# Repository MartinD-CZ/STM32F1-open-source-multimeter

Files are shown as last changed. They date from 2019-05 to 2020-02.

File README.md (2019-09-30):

# STM32 OpenSource Multimeter
*see the article [here](http://embedblog.eu/?p=438) or the video [here](https://youtu.be/qQX5iS70-mg)*
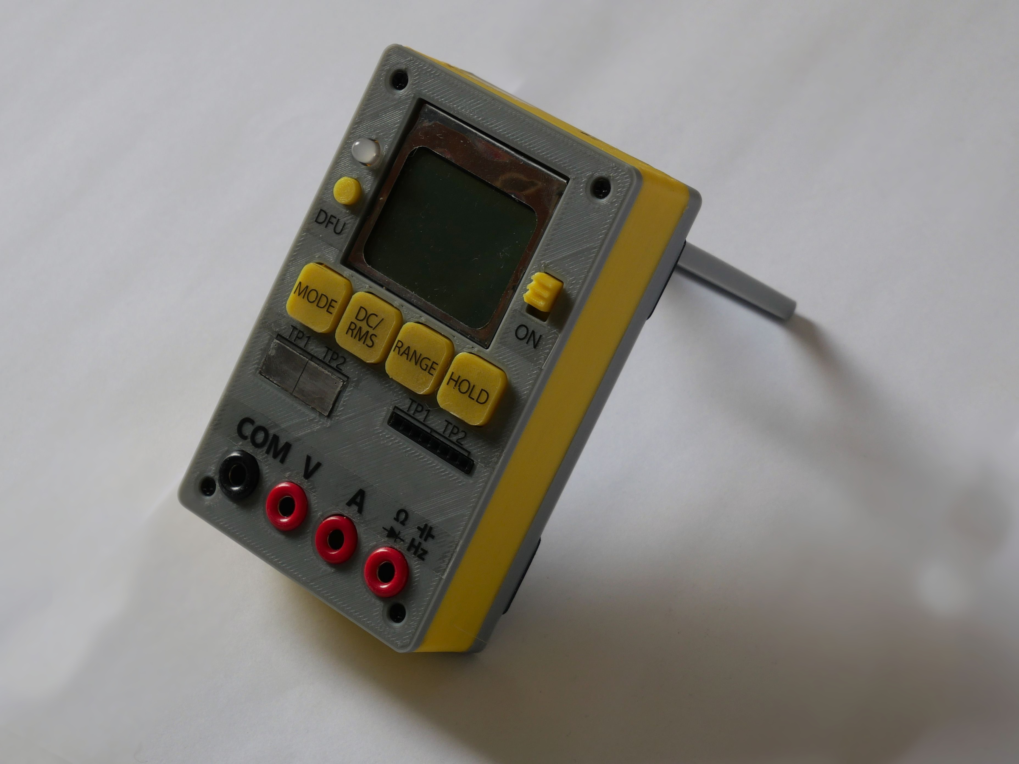
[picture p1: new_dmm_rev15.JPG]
A picture of the finished device


## Specs (revision 1.5 - latest stable)
1. voltage measurement: ±60 V, ±6 V, ±600 mV, ±60 m ranges, with DC or RMS data acquisition
2. current measurement: ±250 or ±2500 mA ranges, again with DC or RMS
3. can measure voltage and current simultaneously and display the product, ie power
4. measures continuity and displays the resistance and voltage drop
5. can perform simple component testing
6. frequency measurement up to 10 MHz

Additional features: isolated USB serial port; ; 2 kB EEPROM; 4 bit expansion port; battery voltage measurement & charging via USB; firmware update via USB; integrated kickstand; hold function

*Note: when this project started, it used STM32F1. Now it uses STM32F3, but I cannot rename the repository, so I hope it won't mislead anyone.*

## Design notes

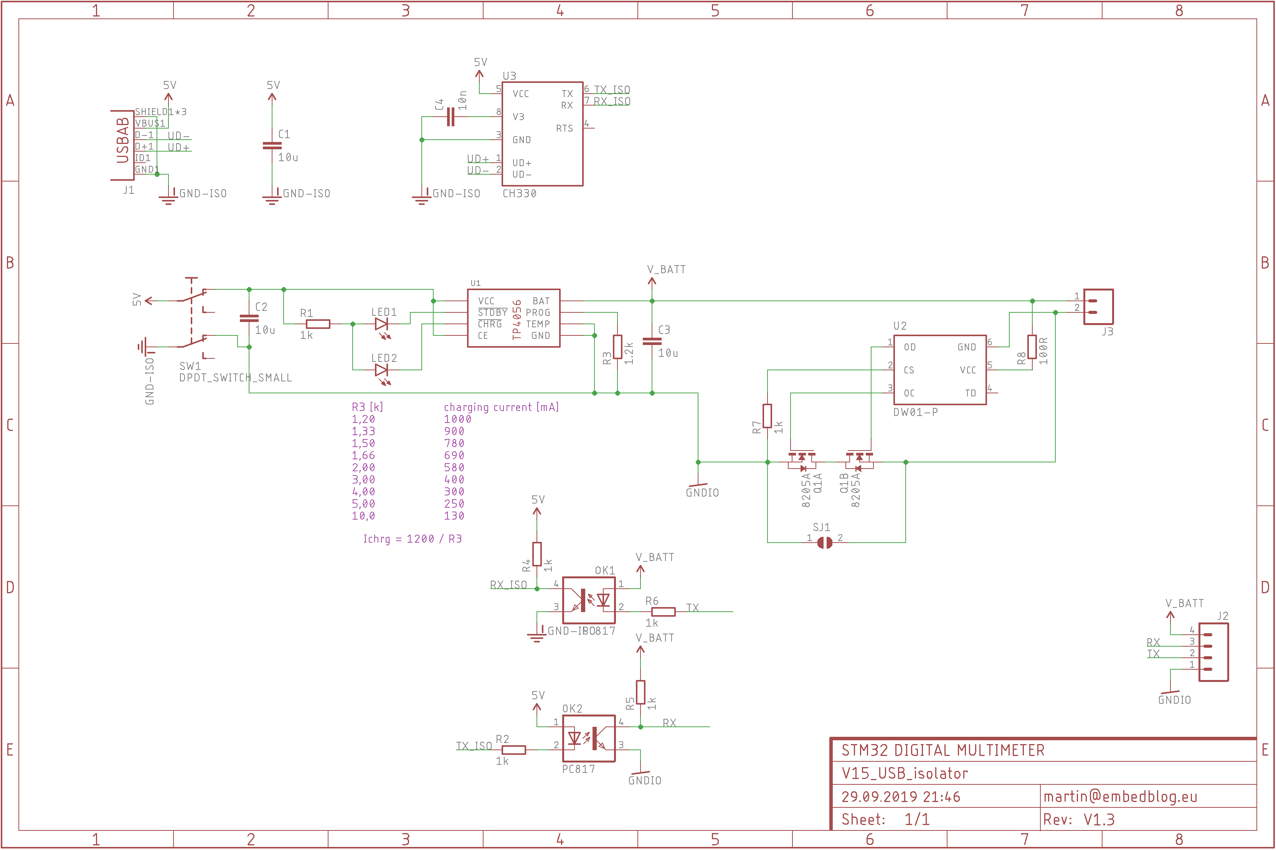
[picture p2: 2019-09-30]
hardware/schematics_USB_isolator.png

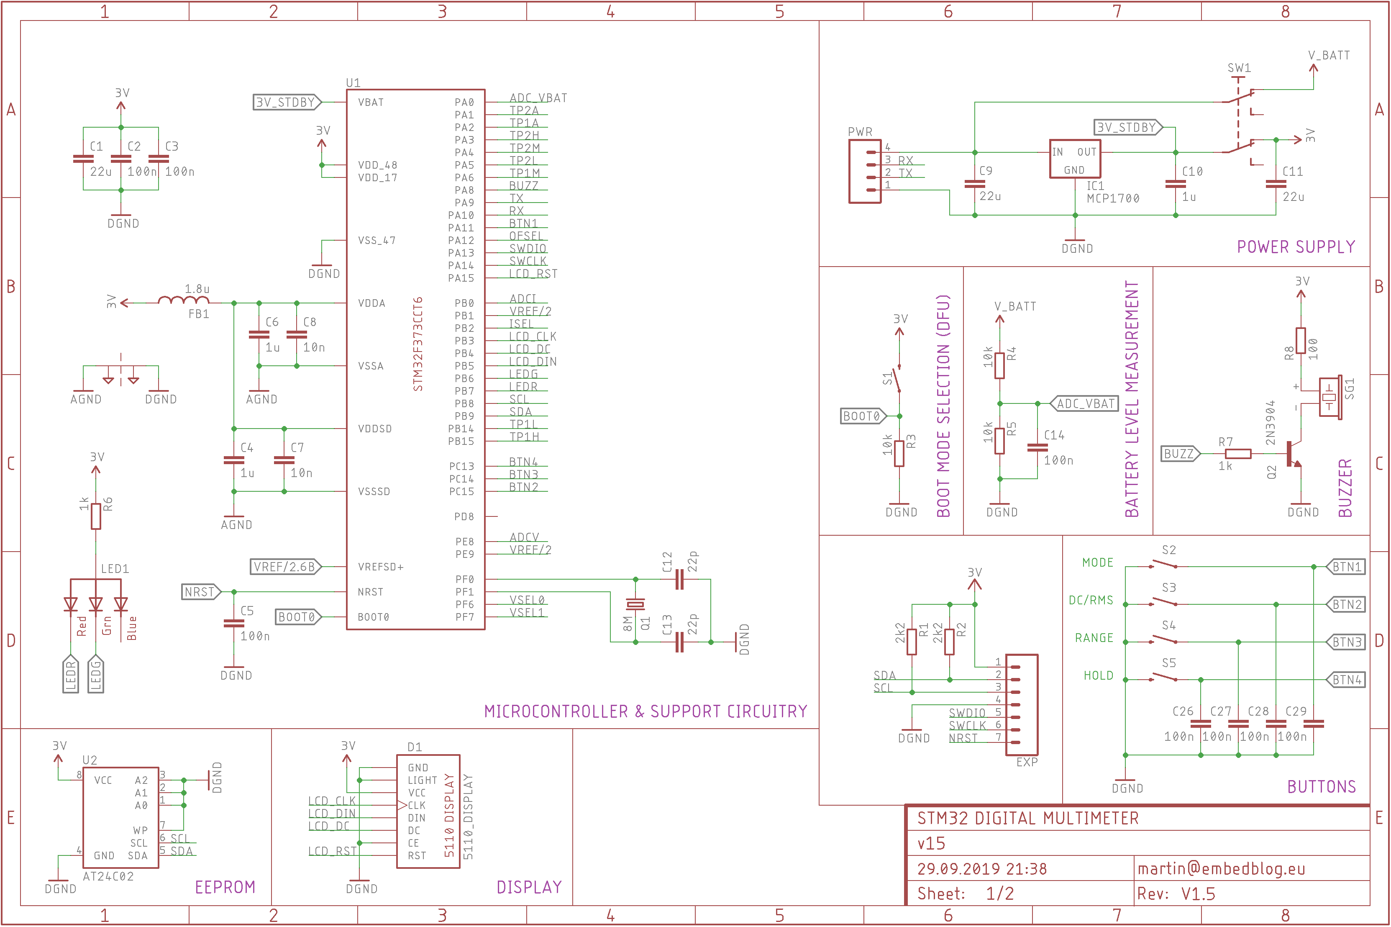
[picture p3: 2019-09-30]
hardware/schematics_sheet1.png

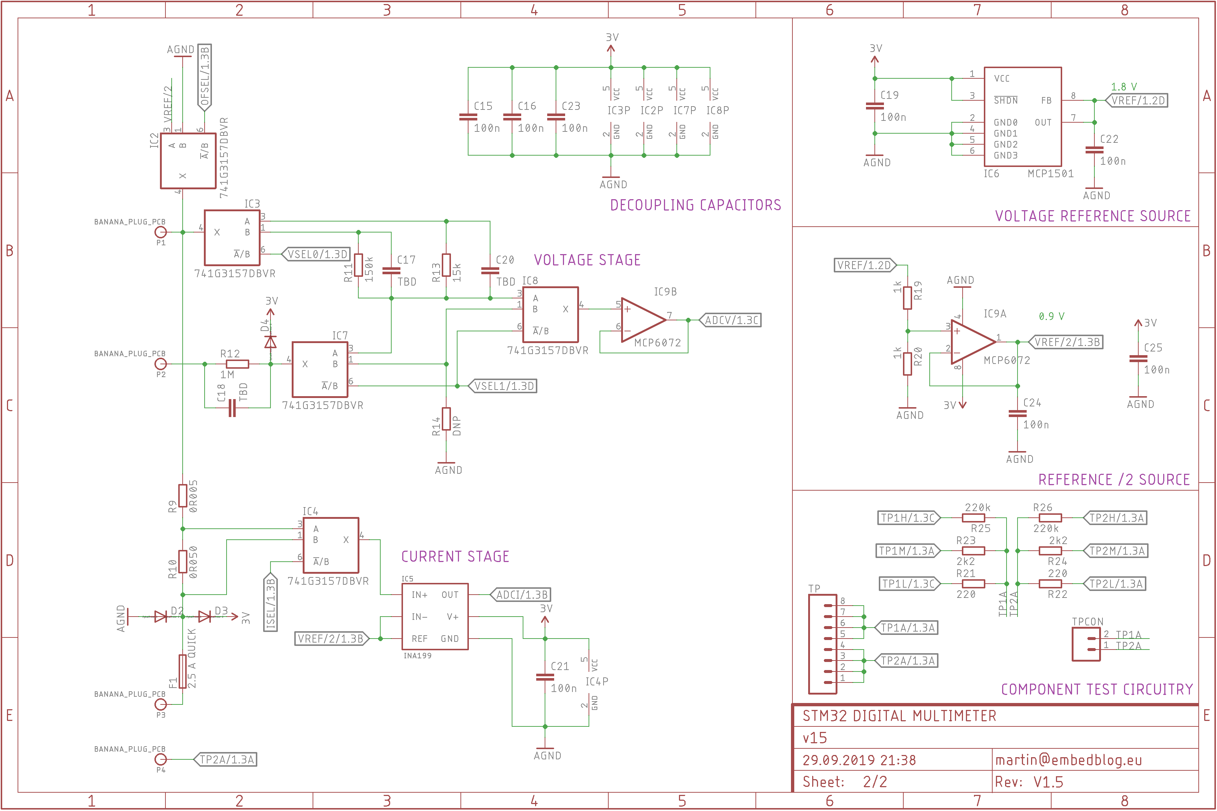
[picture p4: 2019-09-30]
hardware/schematics_sheet2.png

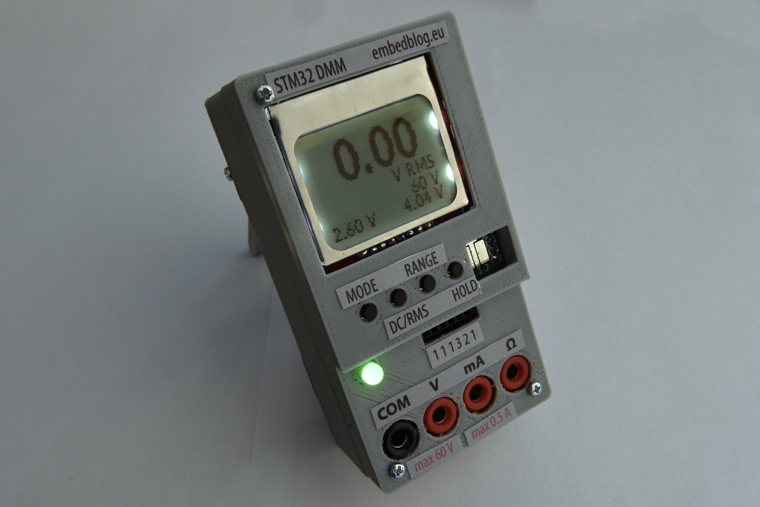
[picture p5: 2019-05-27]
dmm.JPG

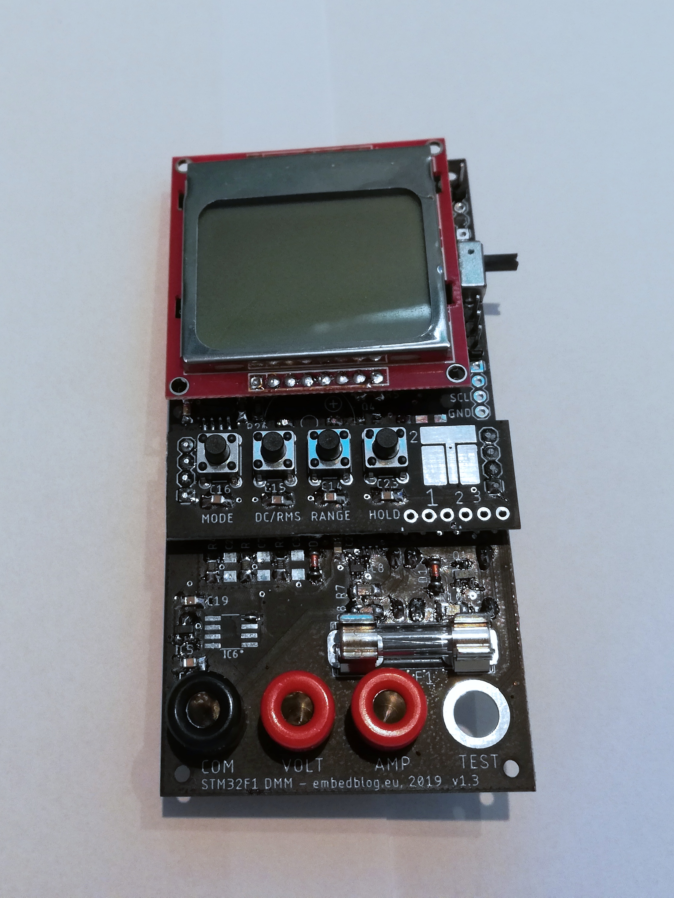
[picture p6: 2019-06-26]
dmm_rev13.JPG

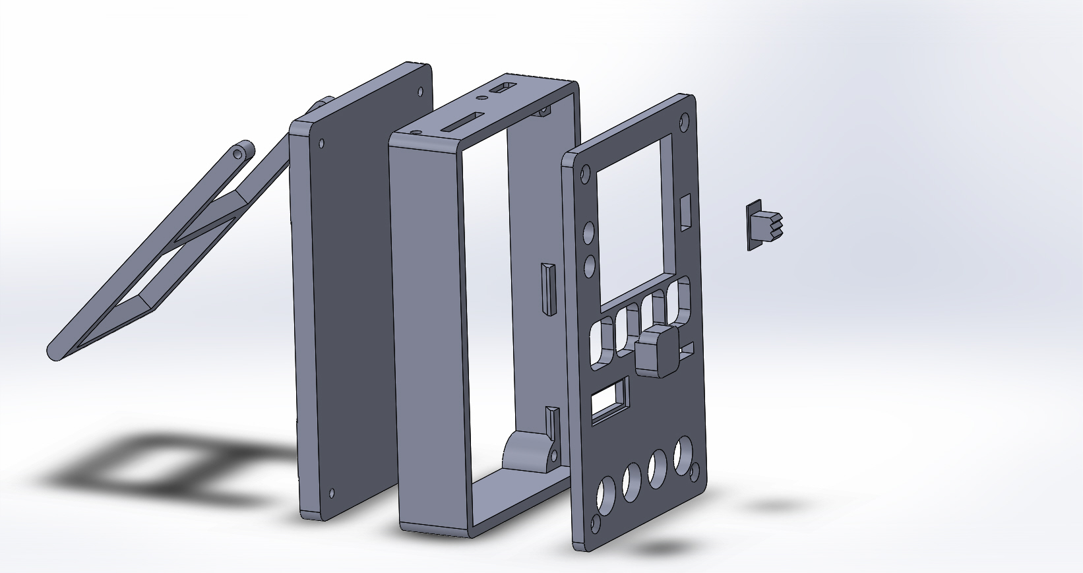
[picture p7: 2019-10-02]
case/case_exploded.JPG

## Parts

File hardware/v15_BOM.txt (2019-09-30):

Part  Value                           Device                          Package                  Description                                                                                                     MF MPN OC_FARNELL OC_NEWARK PROD_ID     SF_ID     SF_SKU   
C1    22u                             C-EUC1206                       C1206                    CAPACITOR, European symbol                                                                                                                                                 
C2    100n                            C-EUC1206                       C1206                    CAPACITOR, European symbol                                                                                                                                                 
C3    100n                            C-EUC1206                       C1206                    CAPACITOR, European symbol                                                                                                                                                 
C4    1u                              C-EUC1206                       C1206                    CAPACITOR, European symbol                                                                                                                                                 
C5    100n                            C-EUC1206                       C1206                    CAPACITOR, European symbol                                                                                                                                                 
C6    1u                              C-EUC1206                       C1206                    CAPACITOR, European symbol                                                                                                                                                 
C7    10n                             C-EUC1206                       C1206                    CAPACITOR, European symbol                                                                                                                                                 
C8    10n                             C-EUC1206                       C1206                    CAPACITOR, European symbol                                                                                                                                                 
C9    22u                             C-EUC1206                       C1206                    CAPACITOR, European symbol                                                                                                                                                 
C10   1u                              C-EUC1206                       C1206                    CAPACITOR, European symbol                                                                                                                                                 
C11   22u                             C-EUC1206                       C1206                    CAPACITOR, European symbol                                                                                                                                                 
C12   22p                             C-EUC1206                       C1206                    CAPACITOR, European symbol                                                                                                                                                 
C13   22p                             C-EUC1206                       C1206                    CAPACITOR, European symbol                                                                                                                                                 
C14   100n                            C-EUC1206                       C1206                    CAPACITOR, European symbol                                                                                                                                                 
C15   100n                            CAP1206                         1206                     Capacitor                                                                                                                                                                  
C16   100n                            CAP1206                         1206                     Capacitor                                                                                                                                                                  
C17   TBD                             CAP1206                         1206                     Capacitor                                                                                                                                                                  
C18   TBD                             CAP1206                         1206                     Capacitor                                                                                                                                                                  
C19   100n                            C-EUC1206                       C1206                    CAPACITOR, European symbol                                                                                                                                                 
C20   TBD                             CAP1206                         1206                     Capacitor                                                                                                                                                                  
C21   100n                            CAP1206                         1206                     Capacitor                                                                                                                                                                  
C22   100n                            C-EUC1206                       C1206                    CAPACITOR, European symbol                                                                                                                                                 
C23   100n                            CAP1206                         1206                     Capacitor                                                                                                                                                                  
C24   100n                            C-EUC1206                       C1206                    CAPACITOR, European symbol                                                                                                                                                 
C25   100n                            C-EUC1206                       C1206                    CAPACITOR, European symbol                                                                                                                                                 
C26   100n                            C-EUC1206                       C1206                    CAPACITOR, European symbol                                                                                                                                                 
C27   100n                            C-EUC1206                       C1206                    CAPACITOR, European symbol                                                                                                                                                 
C28   100n                            C-EUC1206                       C1206                    CAPACITOR, European symbol                                                                                                                                                 
C29   100n                            C-EUC1206                       C1206                    CAPACITOR, European symbol                                                                                                                                                 
D1    5110_DISPLAY                    5110_DISPLAY                    5110_LAYOUT                                                                                                                                                                                         
D2                                    DIODE-MINIMELF                  MINIMELF                 DIODE                                                                                                                                                                      
D3                                    DIODE-MINIMELF                  MINIMELF                 DIODE                                                                                                                                                                      
D4                                    DIODE-MINIMELF                  MINIMELF                 DIODE                                                                                                                                                                      
EXP                                   CONN_07                         1X07                     Multi connection point. Often used as Generic Header-pin footprint for 0.1 inch spaced/style header connections                                                            
F1    2.5 A QUICK                     FUSESHK20L                      SHK20L                   Fuse                                                                                                                   unknown    unknown                                  
FB1   1.8u                            FERRITE-BEADC                   1206                     Ferrite beads in various packages                                                                                                                                          
IC1   MCP1700                         XC63FPM                         SOT23                    Positiv Voltage Regulators                                                                                                                                                 
IC2   741G3157DBVR                    741G3157DBVR                    DBV_R-PDSO-G6            Single-Pole, Double-Throw Analog Switch                                                                                                                                    
IC3   741G3157DBVR                    741G3157DBVR                    DBV_R-PDSO-G6            Single-Pole, Double-Throw Analog Switch                                                                                                                                    
IC4   741G3157DBVR                    741G3157DBVR                    DBV_R-PDSO-G6            Single-Pole, Double-Throw Analog Switch                                                                                                                                    
IC5   INA199                          INA199                          SC70-6                                                                                                                                                                                              
IC6   MCP1501                         MCP1501                         SO08                                                                                                                                                                                                
IC7   741G3157DBVR                    741G3157DBVR                    DBV_R-PDSO-G6            Single-Pole, Double-Throw Analog Switch                                                                                                                                    
IC8   741G3157DBVR                    741G3157DBVR                    DBV_R-PDSO-G6            Single-Pole, Double-Throw Analog Switch                                                                                                                                    
IC9   MCP6072                         OPAMP-DUALU                     SO08                     Generic op-amp footprint                                                                                                                                                   
LED1  RGBLED_CA-5MM                   RGBLED_CA-5MM                   LED5MMRGB                RGB LED, common-anode5MM Staggered pins5mm Piranha package                                                                                                                 
P1    BANANA_PLUG_PCB                 BANANA_PLUG_PCB                 BANANA_6MMHOLE                                                                                                                                                                                      
P2    BANANA_PLUG_PCB                 BANANA_PLUG_PCB                 BANANA_6MMHOLE                                                                                                                                                                                      
P3    BANANA_PLUG_PCB                 BANANA_PLUG_PCB                 BANANA_6MMHOLE                                                                                                                                                                                      
P4    BANANA_PLUG_PCB                 BANANA_PLUG_PCB                 BANANA_6MMHOLE                                                                                                                                                                                      
PT1   2PT_GND_TIE                     2PT_GND_TIE                     2PT_GND_TIE              Package for connecting two ground nets in one place.                                                                                                                       
PWR                                   M04PTH                          1X04@1                   Header 4                                                                                                                                    CONN-09696                     
Q1    8M                              CRYSTALHC49U-V                  HC49U-V                  CRYSTAL                                                                                                                1666969    unknown                                  
Q2    2N3904                          2N3904-MMBT                     SOT23                    NPN TRANSISTOR                                                                                                                                                             
R1    2k2                             R-EU_R1206                      R1206                    RESISTOR, European symbol                                                                                                                                                  
R2    2k2                             R-EU_R1206                      R1206                    RESISTOR, European symbol                                                                                                                                                  
R3    10k                             R-EU_R1206                      R1206                    RESISTOR, European symbol                                                                                                                                                  
R4    10k                             R-EU_R1206                      R1206                    RESISTOR, European symbol                                                                                                                                                  
R5    10k                             R-EU_R1206                      R1206                    RESISTOR, European symbol                                                                                                                                                  
R6    1k                              R-EU_R1206                      R1206                    RESISTOR, European symbol                                                                                                                                                  
R7    1k                              R-EU_R1206                      R1206                    RESISTOR, European symbol                                                                                                                                                  
R8    100                             R-EU_R1206                      R1206                    RESISTOR, European symbol                                                                                                                                                  
R9    0R005                           R-EU_R1206                      R1206                    RESISTOR, European symbol                                                                                                                                                  
R10   0R050                           R-EU_R1206                      R1206                    RESISTOR, European symbol                                                                                                                                                  
R11   150k                            R-EU_R1206                      R1206                    RESISTOR, European symbol                                                                                                                                                  
R12   1M                              R-EU_R1206                      R1206                    RESISTOR, European symbol                                                                                                                                                  
R13   15k                             R-EU_R1206                      R1206                    RESISTOR, European symbol                                                                                                                                                  
R14   DNP                             R-EU_R1206                      R1206                    RESISTOR, European symbol                                                                                                                                                  
R19   1k                              R-EU_R1206                      R1206                    RESISTOR, European symbol                                                                                                                                                  
R20   1k                              R-EU_R1206                      R1206                    RESISTOR, European symbol                                                                                                                                                  
R21   220                             R-EU_R1206                      R1206                    RESISTOR, European symbol                                                                                                                                                  
R22   220                             R-EU_R1206                      R1206                    RESISTOR, European symbol                                                                                                                                                  
R23   2k2                             R-EU_R1206                      R1206                    RESISTOR, European symbol                                                                                                                                                  
R24   2k2                             R-EU_R1206                      R1206                    RESISTOR, European symbol                                                                                                                                                  
R25   220k                            R-EU_R1206                      R1206                    RESISTOR, European symbol                                                                                                                                                  
R26   220k                            R-EU_R1206                      R1206                    RESISTOR, European symbol                                                                                                                                                  
S1    MOMENTARY-SWITCH-SPST-PTH-6.0MM MOMENTARY-SWITCH-SPST-PTH-6.0MM TACTILE_SWITCH_PTH_6.0MM Momentary Switch (Pushbutton) - SPST                                                                                                         SWCH-08441           COM-00097
S2    MOMENTARY-SWITCH-SPST-SMD-12MM  MOMENTARY-SWITCH-SPST-SMD-12MM  TACTILE_SWITCH_SMD_12MM  Momentary Switch (Pushbutton) - SPST                                                                                                        SWCH-11967            COM-12993
S3    MOMENTARY-SWITCH-SPST-SMD-12MM  MOMENTARY-SWITCH-SPST-SMD-12MM  TACTILE_SWITCH_SMD_12MM  Momentary Switch (Pushbutton) - SPST                                                                                                        SWCH-11967            COM-12993
S4    MOMENTARY-SWITCH-SPST-SMD-12MM  MOMENTARY-SWITCH-SPST-SMD-12MM  TACTILE_SWITCH_SMD_12MM  Momentary Switch (Pushbutton) - SPST                                                                                                        SWCH-11967            COM-12993
S5    MOMENTARY-SWITCH-SPST-SMD-12MM  MOMENTARY-SWITCH-SPST-SMD-12MM  TACTILE_SWITCH_SMD_12MM  Momentary Switch (Pushbutton) - SPST                                                                                                        SWCH-11967            COM-12993
SG1   F/CM12P                         F/CM12P                         F/CM12P                  BUZZER Source: Buerklin                                                                                                unknown    unknown                                  
SW1   DPDT_SWITCH_SMALL               DPDT_SWITCH_SMALL               DPDT_SMALL                                                                                                                                                                                          
TP                                    CONN_08SMD-STRAIGHT-FEMALE      1X08_SMD                 Multi connection point. Often used as Generic Header-pin footprint for 0.1 inch spaced/style header connections                             CONN-10204  PRT-11543          
TPCON                                 CONN_02                         1X02                     Multi connection point. Often used as Generic Header-pin footprint for 0.1 inch spaced/style header connections                                                            
U1    STM32F373CCT6                   STM32F373CCT6                   LQFP-48                                                                                                                                                                                             
U2    AT24C02                         24LCXX                          SOIC8                    Serial I2C bus eeprom

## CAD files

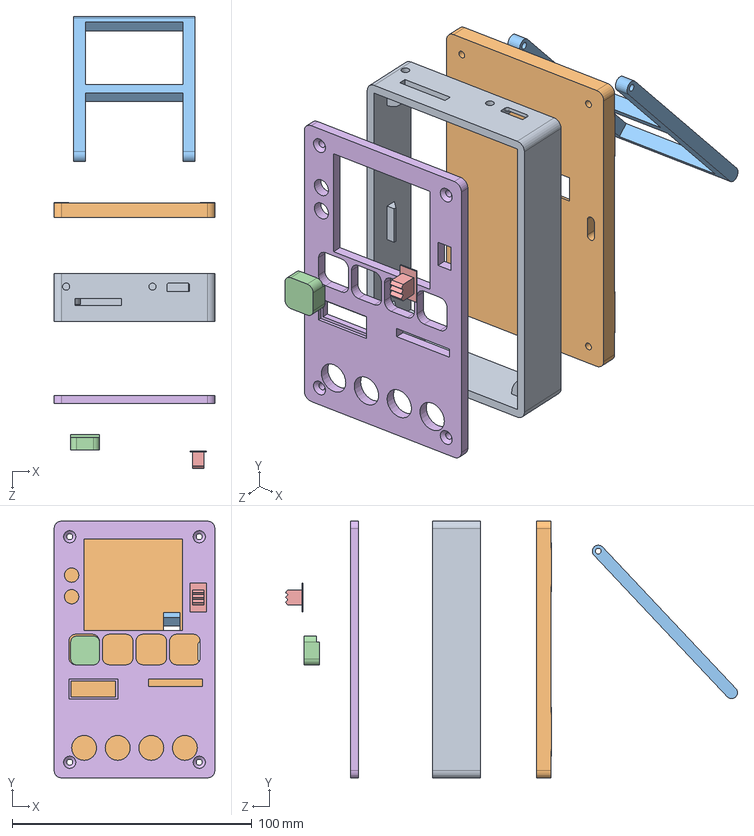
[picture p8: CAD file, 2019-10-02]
case/SolidWorks/set.SLDASM
67.0 x 107.0 x 188.4 mm
bottom
bottom_leg
button_attachment
slide_attachment
top

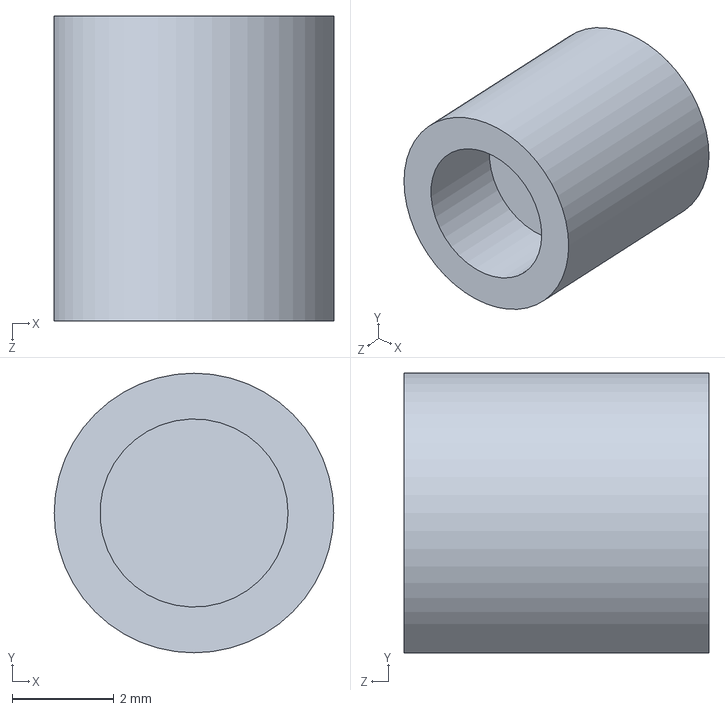
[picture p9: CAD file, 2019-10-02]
case/SolidWorks/button_round_attachment.SLDPRT
5.50 x 5.50 x 6.00 mm

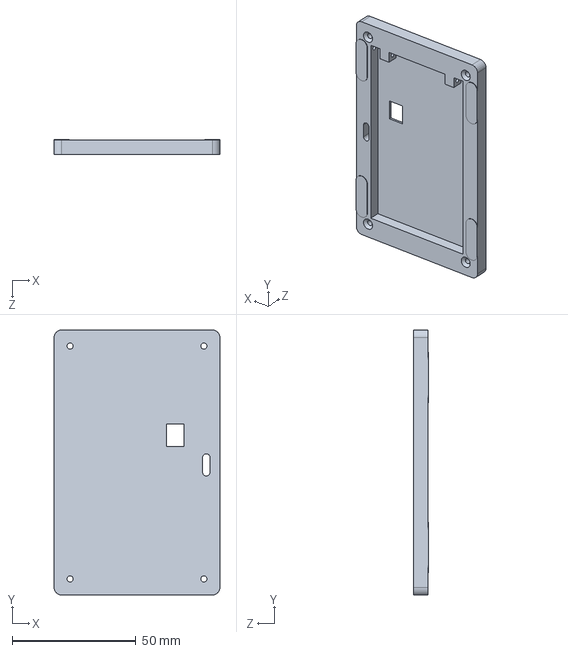
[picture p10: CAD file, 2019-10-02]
case/SolidWorks/bottom.SLDPRT
67.0 x 107.0 x 6.20 mm

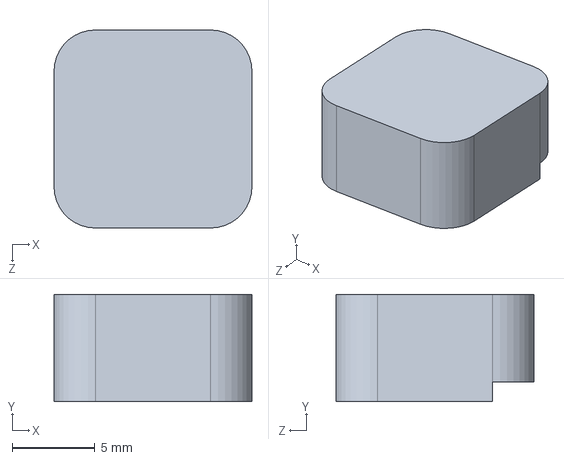
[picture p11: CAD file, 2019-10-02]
case/SolidWorks/button_attachment.SLDPRT
12.0 x 6.50 x 12.0 mm

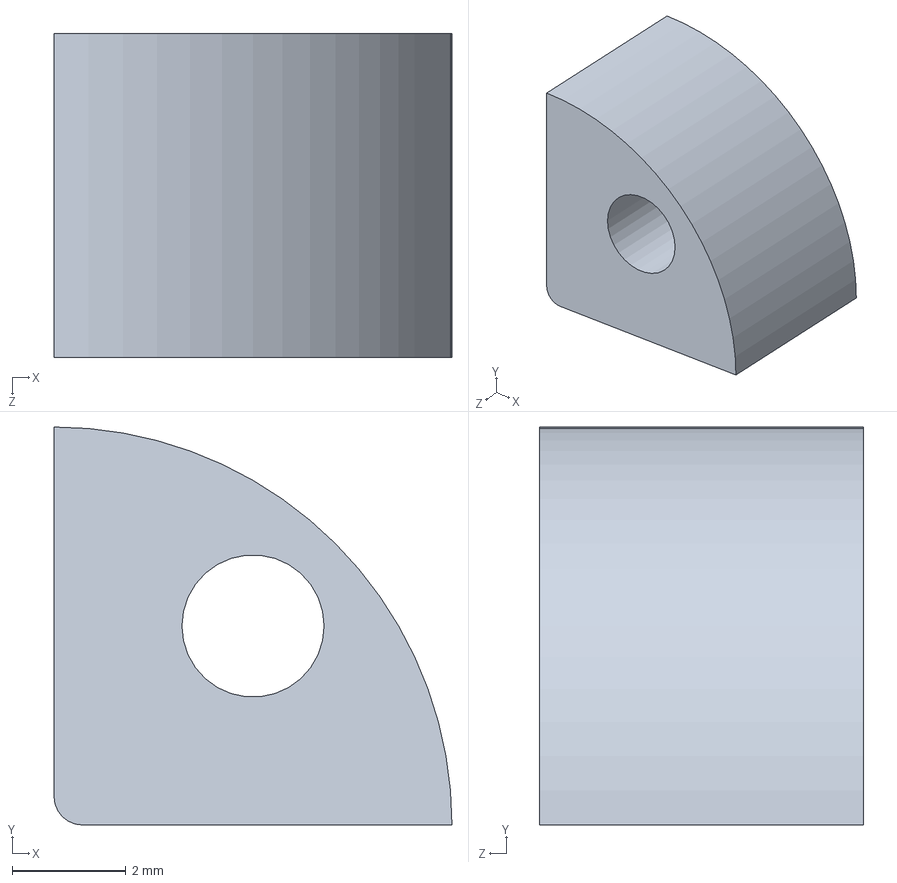
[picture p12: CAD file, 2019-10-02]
case/SolidWorks/distancer.SLDPRT
7.00 x 7.00 x 5.70 mm

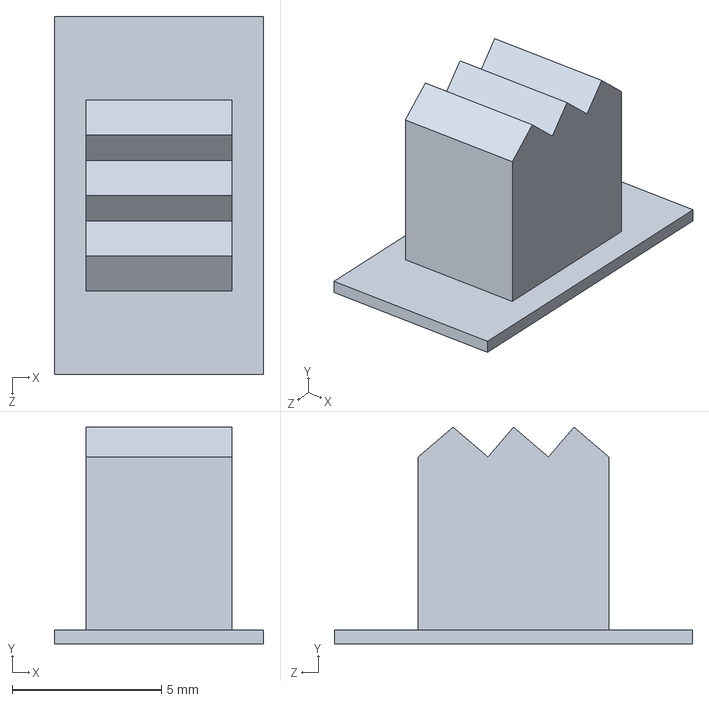
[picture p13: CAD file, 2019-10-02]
case/SolidWorks/slide_attachment.SLDPRT
7.00 x 7.26 x 12.0 mm

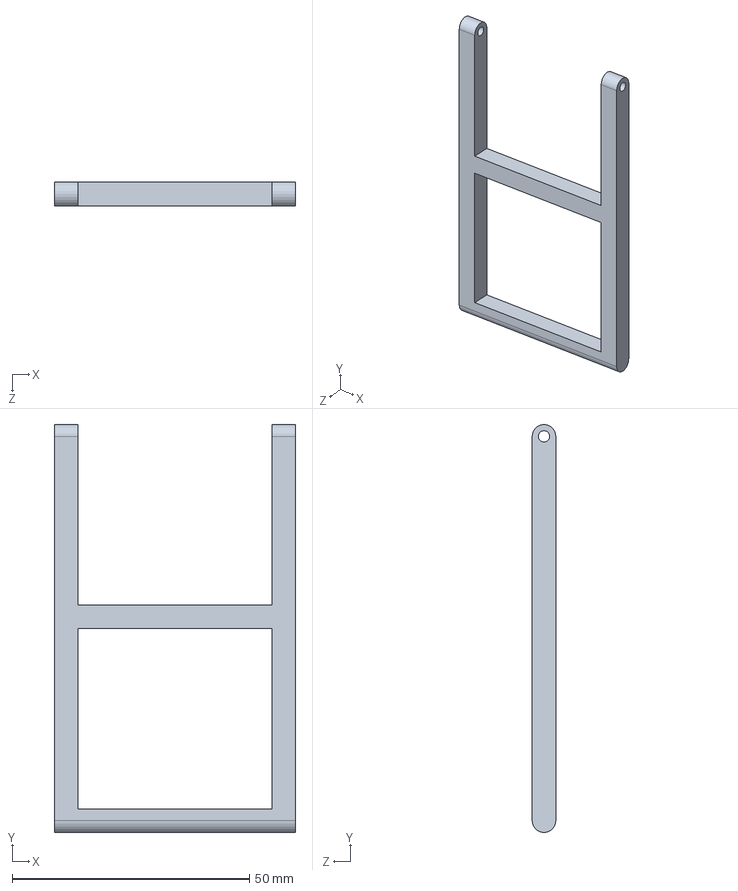
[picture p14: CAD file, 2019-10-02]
case/SolidWorks/bottom_leg.SLDPRT
50.8 x 86.0 x 5.00 mm

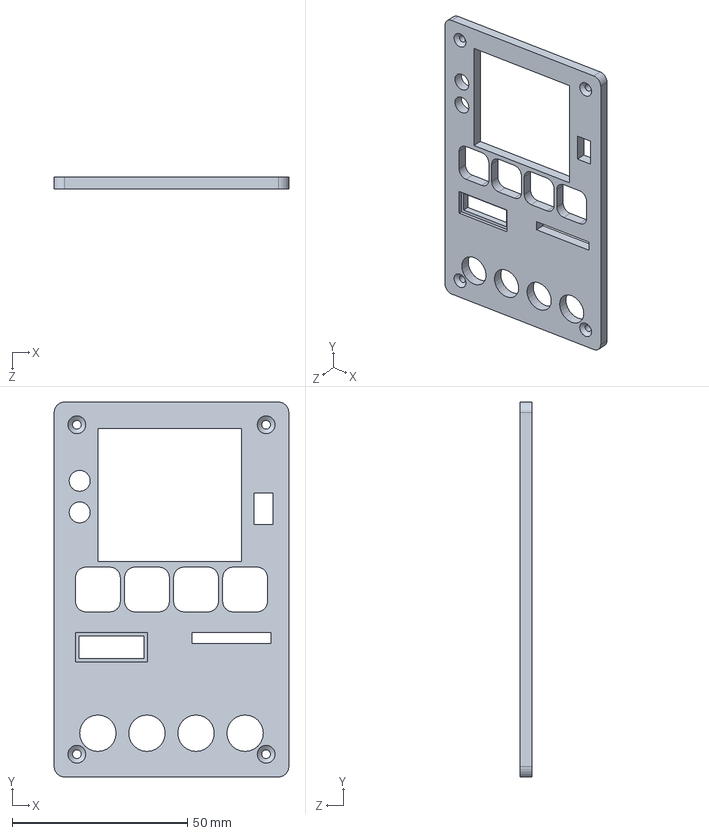
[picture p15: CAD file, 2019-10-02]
case/SolidWorks/top.SLDPRT
67.0 x 107.0 x 3.50 mm

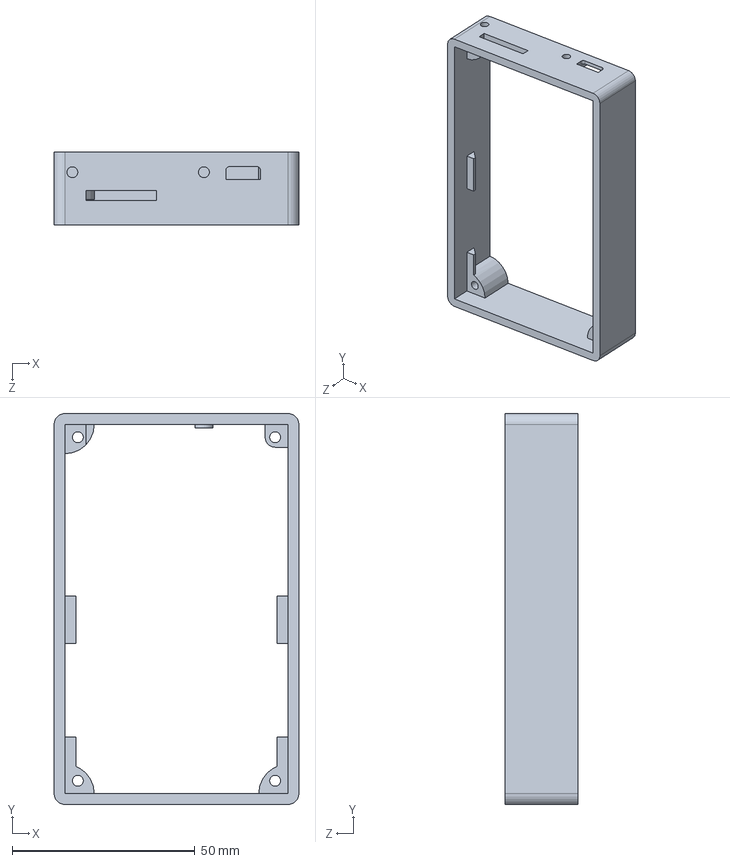
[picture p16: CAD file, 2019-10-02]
case/SolidWorks/body.SLDPRT
67.0 x 107.0 x 20.0 mm

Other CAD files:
case/STLs/body.STL
case/STLs/bottom.STL
case/STLs/bottom_leg.STL
case/STLs/button_attachment.STL
case/STLs/button_round_attachment.STL
case/STLs/distancer.STL
case/STLs/slide_attachment.STL
case/STLs/top.STL

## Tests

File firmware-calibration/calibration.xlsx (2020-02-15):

bottom | ADC value | -26190
 | real value | -0.2474
top | ADC value | 26270
 | real value | 0.2467
 | gain: | 0.0000094186 | for milivolt/miliamp, multiply both values by 1000!
 | offset: | -0.0007267442

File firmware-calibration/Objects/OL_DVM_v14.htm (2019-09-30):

# Static Call Graph for image .\Objects\OL_DVM_v14.axf

#<CALLGRAPH># ARM Linker, 5060422: Last Updated: Sun Sep 29 23:10:01 2019

### Maximum Stack Usage = 260 bytes + Unknown(Functions without stacksize, Cycles, Untraceable Function Pointers)

### Call chain for Maximum Stack Depth:

__rt_entry_main ⇒ main ⇒ LCD_5110::printxy(char*, unsigned char, unsigned char) ⇒ LCD_5110::print(char*) ⇒ LCD_5110::drawChar(short, short, unsigned char, bool, bool, unsigned char) ⇒ LCD_5110::drawFillRect(short, short, short, short, bool) ⇒ LCD_5110::drawLine(short, short, short, short, bool) ⇒ LCD_5110::drawPixel(short, short, unsigned short)

### Functions with no stack information

- __user_initial_stackheap

### Mutually Recursive functions

- NMI_Handler ⇒ NMI_Handler
- HardFault_Handler ⇒ HardFault_Handler
- MemManage_Handler ⇒ MemManage_Handler
- BusFault_Handler ⇒ BusFault_Handler
- UsageFault_Handler ⇒ UsageFault_Handler
- SVC_Handler ⇒ SVC_Handler
- DebugMon_Handler ⇒ DebugMon_Handler
- PendSV_Handler ⇒ PendSV_Handler
- SysTick_Handler ⇒ SysTick_Handler
- ADC1_IRQHandler ⇒ ADC1_IRQHandler

### Function Pointers

- ADC1_IRQHandler from startup_stm32f373xc.o(.text) referenced from startup_stm32f373xc.o(RESET)
- BusFault_Handler from startup_stm32f373xc.o(.text) referenced from startup_stm32f373xc.o(RESET)
- CAN_RX0_IRQHandler from startup_stm32f373xc.o(.text) referenced from startup_stm32f373xc.o(RESET)
- CAN_RX1_IRQHandler from startup_stm32f373xc.o(.text) referenced from startup_stm32f373xc.o(RESET)
- CAN_SCE_IRQHandler from startup_stm32f373xc.o(.text) referenced from startup_stm32f373xc.o(RESET)
- CAN_TX_IRQHandler from startup_stm32f373xc.o(.text) referenced from startup_stm32f373xc.o(RESET)
- CEC_IRQHandler from startup_stm32f373xc.o(.text) referenced from startup_stm32f373xc.o(RESET)
- COMP1_2_IRQHandler from startup_stm32f373xc.o(.text) referenced from startup_stm32f373xc.o(RESET)
- DMA1_Channel1_IRQHandler from startup_stm32f373xc.o(.text) referenced from startup_stm32f373xc.o(RESET)
- DMA1_Channel2_IRQHandler from startup_stm32f373xc.o(.text) referenced from startup_stm32f373xc.o(RESET)
- DMA1_Channel3_IRQHandler from startup_stm32f373xc.o(.text) referenced from startup_stm32f373xc.o(RESET)
- DMA1_Channel4_IRQHandler from startup_stm32f373xc.o(.text) referenced from startup_stm32f373xc.o(RESET)
- DMA1_Channel5_IRQHandler from startup_stm32f373xc.o(.text) referenced from startup_stm32f373xc.o(RESET)
- DMA1_Channel6_IRQHandler from startup_stm32f373xc.o(.text) referenced from startup_stm32f373xc.o(RESET)
- DMA1_Channel7_IRQHandler from startup_stm32f373xc.o(.text) referenced from startup_stm32f373xc.o(RESET)
- DMA2_Channel1_IRQHandler from startup_stm32f373xc.o(.text) referenced from startup_stm32f373xc.o(RESET)
- DMA2_Channel2_IRQHandler from startup_stm32f373xc.o(.text) referenced from startup_stm32f373xc.o(RESET)
- DMA2_Channel3_IRQHandler from startup_stm32f373xc.o(.text) referenced from startup_stm32f373xc.o(RESET)
- DMA2_Channel4_IRQHandler from startup_stm32f373xc.o(.text) referenced from startup_stm32f373xc.o(RESET)
- DMA2_Channel5_IRQHandler from startup_stm32f373xc.o(.text) referenced from startup_stm32f373xc.o(RESET)
- DebugMon_Handler from startup_stm32f373xc.o(.text) referenced from startup_stm32f373xc.o(RESET)
- EXTI0_IRQHandler from startup_stm32f373xc.o(.text) referenced from startup_stm32f373xc.o(RESET)
- EXTI15_10_IRQHandler from startup_stm32f373xc.o(.text) referenced from startup_stm32f373xc.o(RESET)
- EXTI1_IRQHandler from startup_stm32f373xc.o(.text) referenced from startup_stm32f373xc.o(RESET)
- EXTI2_TSC_IRQHandler from startup_stm32f373xc.o(.text) referenced from startup_stm32f373xc.o(RESET)
- EXTI3_IRQHandler from startup_stm32f373xc.o(.text) referenced from startup_stm32f373xc.o(RESET)
- EXTI4_IRQHandler from startup_stm32f373xc.o(.text) referenced from startup_stm32f373xc.o(RESET)
- EXTI9_5_IRQHandler from startup_stm32f373xc.o(.text) referenced from startup_stm32f373xc.o(RESET)
- FLASH_IRQHandler from startup_stm32f373xc.o(.text) referenced from startup_stm32f373xc.o(RESET)
- FPU_IRQHandler from startup_stm32f373xc.o(.text) referenced from startup_stm32f373xc.o(RESET)
- HardFault_Handler from startup_stm32f373xc.o(.text) referenced from startup_stm32f373xc.o(RESET)
- I2C1_ER_IRQHandler from startup_stm32f373xc.o(.text) referenced from startup_stm32f373xc.o(RESET)
- I2C1_EV_IRQHandler from startup_stm32f373xc.o(.text) referenced from startup_stm32f373xc.o(RESET)
- I2C2_ER_IRQHandler from startup_stm32f373xc.o(.text) referenced from startup_stm32f373xc.o(RESET)
- I2C2_EV_IRQHandler from startup_stm32f373xc.o(.text) referenced from startup_stm32f373xc.o(RESET)
- MemManage_Handler from startup_stm32f373xc.o(.text) referenced from startup_stm32f373xc.o(RESET)
- NMI_Handler from startup_stm32f373xc.o(.text) referenced from startup_stm32f373xc.o(RESET)
- PVD_IRQHandler from startup_stm32f373xc.o(.text) referenced from startup_stm32f373xc.o(RESET)
- PendSV_Handler from startup_stm32f373xc.o(.text) referenced from startup_stm32f373xc.o(RESET)
- RCC_IRQHandler from startup_stm32f373xc.o(.text) referenced from startup_stm32f373xc.o(RESET)
- RTC_Alarm_IRQHandler from startup_stm32f373xc.o(.text) referenced from startup_stm32f373xc.o(RESET)
- RTC_WKUP_IRQHandler from startup_stm32f373xc.o(.text) referenced from startup_stm32f373xc.o(RESET)
- Reset_Handler from startup_stm32f373xc.o(.text) referenced from startup_stm32f373xc.o(RESET)
- SDADC1_IRQHandler from startup_stm32f373xc.o(.text) referenced from startup_stm32f373xc.o(RESET)
- SDADC2_IRQHandler from startup_stm32f373xc.o(.text) referenced from startup_stm32f373xc.o(RESET)
- SDADC3_IRQHandler from startup_stm32f373xc.o(.text) referenced from startup_stm32f373xc.o(RESET)
- SPI1_IRQHandler from startup_stm32f373xc.o(.text) referenced from startup_stm32f373xc.o(RESET)
- SPI2_IRQHandler from startup_stm32f373xc.o(.text) referenced from startup_stm32f373xc.o(RESET)
- SPI3_IRQHandler from startup_stm32f373xc.o(.text) referenced from startup_stm32f373xc.o(RESET)
- SVC_Handler from startup_stm32f373xc.o(.text) referenced from startup_stm32f373xc.o(RESET)
- SysTick_Handler from startup_stm32f373xc.o(.text) referenced from startup_stm32f373xc.o(RESET)
- SystemInit from system_stm32f3xx.o(i.SystemInit) referenced from startup_stm32f373xc.o(.text)
- TAMP_STAMP_IRQHandler from startup_stm32f373xc.o(.text) referenced from startup_stm32f373xc.o(RESET)
- TIM12_IRQHandler from startup_stm32f373xc.o(.text) referenced from startup_stm32f373xc.o(RESET)
- TIM13_IRQHandler from startup_stm32f373xc.o(.text) referenced from startup_stm32f373xc.o(RESET)
- TIM14_IRQHandler from startup_stm32f373xc.o(.text) referenced from startup_stm32f373xc.o(RESET)
- TIM15_IRQHandler from startup_stm32f373xc.o(.text) referenced from startup_stm32f373xc.o(RESET)
- TIM16_IRQHandler from startup_stm32f373xc.o(.text) referenced from startup_stm32f373xc.o(RESET)
- TIM17_IRQHandler from startup_stm32f373xc.o(.text) referenced from startup_stm32f373xc.o(RESET)
- TIM18_DAC2_IRQHandler from startup_stm32f373xc.o(.text) referenced from startup_stm32f373xc.o(RESET)
- TIM19_IRQHandler from startup_stm32f373xc.o(.text) referenced from startup_stm32f373xc.o(RESET)
- TIM2_IRQHandler from startup_stm32f373xc.o(.text) referenced from startup_stm32f373xc.o(RESET)
- TIM3_IRQHandler from startup_stm32f373xc.o(.text) referenced from startup_stm32f373xc.o(RESET)
- TIM4_IRQHandler from startup_stm32f373xc.o(.text) referenced from startup_stm32f373xc.o(RESET)
- TIM5_IRQHandler from startup_stm32f373xc.o(.text) referenced from startup_stm32f373xc.o(RESET)
- TIM6_DAC1_IRQHandler from startup_stm32f373xc.o(.text) referenced from startup_stm32f373xc.o(RESET)
- TIM7_IRQHandler from startup_stm32f373xc.o(.text) referenced from startup_stm32f373xc.o(RESET)
- USART1_IRQHandler from startup_stm32f373xc.o(.text) referenced from startup_stm32f373xc.o(RESET)
- USART2_IRQHandler from startup_stm32f373xc.o(.text) referenced from startup_stm32f373xc.o(RESET)
- USART3_IRQHandler from startup_stm32f373xc.o(.text) referenced from startup_stm32f373xc.o(RESET)
- USBWakeUp_IRQHandler from startup_stm32f373xc.o(.text) referenced from startup_stm32f373xc.o(RESET)
- USB_HP_IRQHandler from startup_stm32f373xc.o(.text) referenced from startup_stm32f373xc.o(RESET)
- USB_LP_IRQHandler from startup_stm32f373xc.o(.text) referenced from startup_stm32f373xc.o(RESET)
- UsageFault_Handler from startup_stm32f373xc.o(.text) referenced from startup_stm32f373xc.o(RESET)
- WWDG_IRQHandler from startup_stm32f373xc.o(.text) referenced from startup_stm32f373xc.o(RESET)
- __main from __main.o(!!!main) referenced from startup_stm32f373xc.o(.text)

### Global Symbols

__main (Thumb, 8 bytes, Stack size 0 bytes, __main.o(!!!main))

[Calls]

- >> __rt_entry
- >> __scatterload

__scatterload (Thumb, 0 bytes, Stack size unknown bytes, __scatter.o(!!!scatter))

[Called By]

- >> __main

__scatterload_rt2 (Thumb, 44 bytes, Stack size unknown bytes, __scatter.o(!!!scatter), UNUSED)

[Calls]

- >> __rt_entry

__scatterload_rt2_thumb_only (Thumb, 0 bytes, Stack size unknown bytes, __scatter.o(!!!scatter), UNUSED)

__scatterload_null (Thumb, 0 bytes, Stack size unknown bytes, __scatter.o(!!!scatter), UNUSED)

__scatterload_copy (Thumb, 26 bytes, Stack size unknown bytes, __scatter_copy.o(!!handler_copy), UNUSED)

[Calls]

- >> __scatterload_copy

[Called By]

- >> __scatterload_copy

__scatterload_zeroinit (Thumb, 28 bytes, Stack size unknown bytes, __scatter_zi.o(!!handler_zi), UNUSED)

__rt_lib_init (Thumb, 0 bytes, Stack size unknown bytes, libinit.o(.ARM.Collect$$libinit$$00000000))

[Called By]

- >> __rt_entry_li

__rt_lib_init_fp_1 (Thumb, 0 bytes, Stack size unknown bytes, libinit2.o(.ARM.Collect$$libinit$$00000001))

[Calls]

- >> _fp_init

__rt_lib_init_alloca_1 (Thumb, 0 bytes, Stack size unknown bytes, libinit2.o(.ARM.Collect$$libinit$$0000002E))

__rt_lib_init_argv_1 (Thumb, 0 bytes, Stack size unknown bytes, libinit2.o(.ARM.Collect$$libinit$$0000002C))

__rt_lib_init_atexit_1 (Thumb, 0 bytes, Stack size unknown bytes, libinit2.o(.ARM.Collect$$libinit$$0000001B))

__rt_lib_init_clock_1 (Thumb, 0 bytes, Stack size unknown bytes, libinit2.o(.ARM.Collect$$libinit$$00000021))

__rt_lib_init_cpp_1 (Thumb, 0 bytes, Stack size unknown bytes, libinit2.o(.ARM.Collect$$libinit$$00000032))

__rt_lib_init_exceptions_1 (Thumb, 0 bytes, Stack size unknown bytes, libinit2.o(.ARM.Collect$$libinit$$00000030))

__rt_lib_init_fp_trap_1 (Thumb, 0 bytes, Stack size unknown bytes, libinit2.o(.ARM.Collect$$libinit$$0000001F))

__rt_lib_init_getenv_1 (Thumb, 0 bytes, Stack size unknown bytes, libinit2.o(.ARM.Collect$$libinit$$00000023))

__rt_lib_init_heap_1 (Thumb, 0 bytes, Stack size unknown bytes, libinit2.o(.ARM.Collect$$libinit$$0000000A))

__rt_lib_init_lc_collate_1 (Thumb, 0 bytes, Stack size unknown bytes, libinit2.o(.ARM.Collect$$libinit$$00000011))

__rt_lib_init_lc_ctype_1 (Thumb, 0 bytes, Stack size unknown bytes, libinit2.o(.ARM.Collect$$libinit$$00000013))

__rt_lib_init_lc_monetary_1 (Thumb, 0 bytes, Stack size unknown bytes, libinit2.o(.ARM.Collect$$libinit$$00000015))

__rt_lib_init_lc_numeric_1 (Thumb, 0 bytes, Stack size unknown bytes, libinit2.o(.ARM.Collect$$libinit$$00000017))

__rt_lib_init_lc_time_1 (Thumb, 0 bytes, Stack size unknown bytes, libinit2.o(.ARM.Collect$$libinit$$00000019))

__rt_lib_init_preinit_1 (Thumb, 0 bytes, Stack size unknown bytes, libinit2.o(.ARM.Collect$$libinit$$00000004))

__rt_lib_init_rand_1 (Thumb, 0 bytes, Stack size unknown bytes, libinit2.o(.ARM.Collect$$libinit$$0000000E))

__rt_lib_init_return (Thumb, 0 bytes, Stack size unknown bytes, libinit2.o(.ARM.Collect$$libinit$$00000033))

__rt_lib_init_signal_1 (Thumb, 0 bytes, Stack size unknown bytes, libinit2.o(.ARM.Collect$$libinit$$0000001D))

__rt_lib_init_stdio_1 (Thumb, 0 bytes, Stack size unknown bytes, libinit2.o(.ARM.Collect$$libinit$$00000025))

__rt_lib_init_user_alloc_1 (Thumb, 0 bytes, Stack size unknown bytes, libinit2.o(.ARM.Collect$$libinit$$0000000C))

__rt_lib_shutdown (Thumb, 0 bytes, Stack size unknown bytes, libshutdown.o(.ARM.Collect$$libshutdown$$00000000))

[Called By]

- >> __rt_exit_ls

__rt_lib_shutdown_cpp_1 (Thumb, 0 bytes, Stack size unknown bytes, libshutdown2.o(.ARM.Collect$$libshutdown$$00000002))

__rt_lib_shutdown_fp_trap_1 (Thumb, 0 bytes, Stack size unknown bytes, libshutdown2.o(.ARM.Collect$$libshutdown$$00000007))

__rt_lib_shutdown_heap_1 (Thumb, 0 bytes, Stack size unknown bytes, libshutdown2.o(.ARM.Collect$$libshutdown$$0000000F))

__rt_lib_shutdown_return (Thumb, 0 bytes, Stack size unknown bytes, libshutdown2.o(.ARM.Collect$$libshutdown$$00000010))

__rt_lib_shutdown_signal_1 (Thumb, 0 bytes, Stack size unknown bytes, libshutdown2.o(.ARM.Collect$$libshutdown$$0000000A))

__rt_lib_shutdown_stdio_1 (Thumb, 0 bytes, Stack size unknown bytes, libshutdown2.o(.ARM.Collect$$libshutdown$$00000004))

__rt_lib_shutdown_user_alloc_1 (Thumb, 0 bytes, Stack size unknown bytes, libshutdown2.o(.ARM.Collect$$libshutdown$$0000000C))

__rt_entry (Thumb, 0 bytes, Stack size unknown bytes, __rtentry.o(.ARM.Collect$$rtentry$$00000000))

[Called By]

- >> __main
- >> __scatterload_rt2

__rt_entry_presh_1 (Thumb, 0 bytes, Stack size unknown bytes, __rtentry2.o(.ARM.Collect$$rtentry$$00000002))

__rt_entry_sh (Thumb, 0 bytes, Stack size unknown bytes, __rtentry4.o(.ARM.Collect$$rtentry$$00000004))

[Stack]

- Max Depth = 8 + Unknown Stack Size
- Call Chain = __rt_entry_sh ⇒ __user_setup_stackheap

[Calls]

- >> __user_setup_stackheap

__rt_entry_li (Thumb, 0 bytes, Stack size unknown bytes, __rtentry2.o(.ARM.Collect$$rtentry$$0000000A))

[Calls]

- >> __rt_lib_init

__rt_entry_postsh_1 (Thumb, 0 bytes, Stack size unknown bytes, __rtentry2.o(.ARM.Collect$$rtentry$$00000009))

__rt_entry_main (Thumb, 0 bytes, Stack size unknown bytes, __rtentry2.o(.ARM.Collect$$rtentry$$0000000D))

[Stack]

- Max Depth = 260 + Unknown Stack Size
- Call Chain = __rt_entry_main ⇒ main ⇒ LCD_5110::printxy(char*, unsigned char, unsigned char) ⇒ LCD_5110::print(char*) ⇒ LCD_5110::drawChar(short, short, unsigned char, bool, bool, unsigned char) ⇒ LCD_5110::drawFillRect(short, short, short, short, bool) ⇒ LCD_5110::drawLine(short, short, short, short, bool) ⇒ LCD_5110::drawPixel(short, short, unsigned short)

[Calls]

- >> main
- >> exit

__rt_entry_postli_1 (Thumb, 0 bytes, Stack size unknown bytes, __rtentry2.o(.ARM.Collect$$rtentry$$0000000C))

__rt_exit (Thumb, 0 bytes, Stack size unknown bytes, rtexit.o(.ARM.Collect$$rtexit$$00000000))

[Called By]

- >> exit

__rt_exit_ls (Thumb, 0 bytes, Stack size unknown bytes, rtexit2.o(.ARM.Collect$$rtexit$$00000003))

[Calls]

- >> __rt_lib_shutdown

__rt_exit_prels_1 (Thumb, 0 bytes, Stack size unknown bytes, rtexit2.o(.ARM.Collect$$rtexit$$00000002))

__rt_exit_exit (Thumb, 0 bytes, Stack size unknown bytes, rtexit2.o(.ARM.Collect$$rtexit$$00000004))

[Calls]

- >> _sys_exit

Reset_Handler (Thumb, 8 bytes, Stack size 0 bytes, startup_stm32f373xc.o(.text))
[Address Reference Count : 1]

- startup_stm32f373xc.o(RESET)

NMI_Handler (Thumb, 2 bytes, Stack size 0 bytes, startup_stm32f373xc.o(.text))

[Calls]

- >> NMI_Handler

[Called By]

- >> NMI_Handler

[Address Reference Count : 1]

- startup_stm32f373xc.o(RESET)

HardFault_Handler (Thumb, 2 bytes, Stack size 0 bytes, startup_stm32f373xc.o(.text))

[Calls]

- >> HardFault_Handler

[Called By]

- >> HardFault_Handler

[Address Reference Count : 1]

- startup_stm32f373xc.o(RESET)

MemManage_Handler (Thumb, 2 bytes, Stack size 0 bytes, startup_stm32f373xc.o(.text))

[Calls]

- >> MemManage_Handler

[Called By]

- >> MemManage_Handler

[Address Reference Count : 1]

- startup_stm32f373xc.o(RESET)

BusFault_Handler (Thumb, 2 bytes, Stack size 0 bytes, startup_stm32f373xc.o(.text))

[Calls]

- >> BusFault_Handler

[Called By]

- >> BusFault_Handler

[Address Reference Count : 1]

- startup_stm32f373xc.o(RESET)

UsageFault_Handler (Thumb, 2 bytes, Stack size 0 bytes, startup_stm32f373xc.o(.text))

[Calls]

- >> UsageFault_Handler

[Called By]

- >> UsageFault_Handler

[Address Reference Count : 1]

- startup_stm32f373xc.o(RESET)

SVC_Handler (Thumb, 2 bytes, Stack size 0 bytes, startup_stm32f373xc.o(.text))

[Calls]

- >> SVC_Handler

[Called By]

- >> SVC_Handler

[Address Reference Count : 1]

- startup_stm32f373xc.o(RESET)

DebugMon_Handler (Thumb, 2 bytes, Stack size 0 bytes, startup_stm32f373xc.o(.text))

[Calls]

- >> DebugMon_Handler

[Called By]

- >> DebugMon_Handler

[Address Reference Count : 1]

- startup_stm32f373xc.o(RESET)

PendSV_Handler (Thumb, 2 bytes, Stack size 0 bytes, startup_stm32f373xc.o(.text))

[Calls]

- >> PendSV_Handler

[Called By]

- >> PendSV_Handler

[Address Reference Count : 1]

- startup_stm32f373xc.o(RESET)

SysTick_Handler (Thumb, 2 bytes, Stack size 0 bytes, startup_stm32f373xc.o(.text))

[Calls]

- >> SysTick_Handler

[Called By]

- >> SysTick_Handler

[Address Reference Count : 1]

- startup_stm32f373xc.o(RESET)

ADC1_IRQHandler (Thumb, 0 bytes, Stack size 0 bytes, startup_stm32f373xc.o(.text))

[Calls]

- >> ADC1_IRQHandler

[Called By]

- >> ADC1_IRQHandler

[Address Reference Count : 1]

- startup_stm32f373xc.o(RESET)

CAN_RX0_IRQHandler (Thumb, 0 bytes, Stack size 0 bytes, startup_stm32f373xc.o(.text))
[Address Reference Count : 1]

- startup_stm32f373xc.o(RESET)

CAN_RX1_IRQHandler (Thumb, 0 bytes, Stack size 0 bytes, startup_stm32f373xc.o(.text))
[Address Reference Count : 1]

- startup_stm32f373xc.o(RESET)

CAN_SCE_IRQHandler (Thumb, 0 bytes, Stack size 0 bytes, startup_stm32f373xc.o(.text))
[Address Reference Count : 1]

- startup_stm32f373xc.o(RESET)

CAN_TX_IRQHandler (Thumb, 0 bytes, Stack size 0 bytes, startup_stm32f373xc.o(.text))
[Address Reference Count : 1]

- startup_stm32f373xc.o(RESET)

CEC_IRQHandler (Thumb, 0 bytes, Stack size 0 bytes, startup_stm32f373xc.o(.text))
[Address Reference Count : 1]

- startup_stm32f373xc.o(RESET)

COMP1_2_IRQHandler (Thumb, 0 bytes, Stack size 0 bytes, startup_stm32f373xc.o(.text))
[Address Reference Count : 1]

- startup_stm32f373xc.o(RESET)

DMA1_Channel1_IRQHandler (Thumb, 0 bytes, Stack size 0 bytes, startup_stm32f373xc.o(.text))
[Address Reference Count : 1]

- startup_stm32f373xc.o(RESET)

DMA1_Channel2_IRQHandler (Thumb, 0 bytes, Stack size 0 bytes, startup_stm32f373xc.o(.text))
[Address Reference Count : 1]

- startup_stm32f373xc.o(RESET)

DMA1_Channel3_IRQHandler (Thumb, 0 bytes, Stack size 0 bytes, startup_stm32f373xc.o(.text))
[Address Reference Count : 1]

- startup_stm32f373xc.o(RESET)

DMA1_Channel4_IRQHandler (Thumb, 0 bytes, Stack size 0 bytes, startup_stm32f373xc.o(.text))
[Address Reference Count : 1]

- startup_stm32f373xc.o(RESET)

DMA1_Channel5_IRQHandler (Thumb, 0 bytes, Stack size 0 bytes, startup_stm32f373xc.o(.text))
[Address Reference Count : 1]

- startup_stm32f373xc.o(RESET)

DMA1_Channel6_IRQHandler (Thumb, 0 bytes, Stack size 0 bytes, startup_stm32f373xc.o(.text))
[Address Reference Count : 1]

- startup_stm32f373xc.o(RESET)

DMA1_Channel7_IRQHandler (Thumb, 0 bytes, Stack size 0 bytes, startup_stm32f373xc.o(.text))
[Address Reference Count : 1]

- startup_stm32f373xc.o(RESET)

DMA2_Channel1_IRQHandler (Thumb, 0 bytes, Stack size 0 bytes, startup_stm32f373xc.o(.text))
[Address Reference Count : 1]

- startup_stm32f373xc.o(RESET)

DMA2_Channel2_IRQHandler (Thumb, 0 bytes, Stack size 0 bytes, startup_stm32f373xc.o(.text))
[Address Reference Count : 1]

- startup_stm32f373xc.o(RESET)

DMA2_Channel3_IRQHandler (Thumb, 0 bytes, Stack size 0 bytes, startup_stm32f373xc.o(.text))
[Address Reference Count : 1]

- startup_stm32f373xc.o(RESET)

DMA2_Channel4_IRQHandler (Thumb, 0 bytes, Stack size 0 bytes, startup_stm32f373xc.o(.text))
[Address Reference Count : 1]

- startup_stm32f373xc.o(RESET)

DMA2_Channel5_IRQHandler (Thumb, 0 bytes, Stack size 0 bytes, startup_stm32f373xc.o(.text))
[Address Reference Count : 1]

- startup_stm32f373xc.o(RESET)

EXTI0_IRQHandler (Thumb, 0 bytes, Stack size 0 bytes, startup_stm32f373xc.o(.text))
[Address Reference Count : 1]

- startup_stm32f373xc.o(RESET)

EXTI15_10_IRQHandler (Thumb, 0 bytes, Stack size 0 bytes, startup_stm32f373xc.o(.text))
[Address Reference Count : 1]

- startup_stm32f373xc.o(RESET)

EXTI1_IRQHandler (Thumb, 0 bytes, Stack size 0 bytes, startup_stm32f373xc.o(.text))
[Address Reference Count : 1]

- startup_stm32f373xc.o(RESET)

EXTI2_TSC_IRQHandler (Thumb, 0 bytes, Stack size 0 bytes, startup_stm32f373xc.o(.text))
[Address Reference Count : 1]

- startup_stm32f373xc.o(RESET)

EXTI3_IRQHandler (Thumb, 0 bytes, Stack size 0 bytes, startup_stm32f373xc.o(.text))
[Address Reference Count : 1]

- startup_stm32f373xc.o(RESET)

EXTI4_IRQHandler (Thumb, 0 bytes, Stack size 0 bytes, startup_stm32f373xc.o(.text))
[Address Reference Count : 1]

- startup_stm32f373xc.o(RESET)

EXTI9_5_IRQHandler (Thumb, 0 bytes, Stack size 0 bytes, startup_stm32f373xc.o(.text))
[Address Reference Count : 1]

- startup_stm32f373xc.o(RESET)

FLASH_IRQHandler (Thumb, 0 bytes, Stack size 0 bytes, startup_stm32f373xc.o(.text))
[Address Reference Count : 1]

- startup_stm32f373xc.o(RESET)

FPU_IRQHandler (Thumb, 0 bytes, Stack size 0 bytes, startup_stm32f373xc.o(.text))
[Address Reference Count : 1]

- startup_stm32f373xc.o(RESET)

I2C1_ER_IRQHandler (Thumb, 0 bytes, Stack size 0 bytes, startup_stm32f373xc.o(.text))
[Address Reference Count : 1]

- startup_stm32f373xc.o(RESET)

I2C1_EV_IRQHandler (Thumb, 0 bytes, Stack size 0 bytes, startup_stm32f373xc.o(.text))
[Address Reference Count : 1]

- startup_stm32f373xc.o(RESET)

I2C2_ER_IRQHandler (Thumb, 0 bytes, Stack size 0 bytes, startup_stm32f373xc.o(.text))
[Address Reference Count : 1]

- startup_stm32f373xc.o(RESET)

I2C2_EV_IRQHandler (Thumb, 0 bytes, Stack size 0 bytes, startup_stm32f373xc.o(.text))
[Address Reference Count : 1]

- startup_stm32f373xc.o(RESET)

PVD_IRQHandler (Thumb, 0 bytes, Stack size 0 bytes, startup_stm32f373xc.o(.text))
[Address Reference Count : 1]

- startup_stm32f373xc.o(RESET)

RCC_IRQHandler (Thumb, 0 bytes, Stack size 0 bytes, startup_stm32f373xc.o(.text))
[Address Reference Count : 1]

- startup_stm32f373xc.o(RESET)

RTC_Alarm_IRQHandler (Thumb, 0 bytes, Stack size 0 bytes, startup_stm32f373xc.o(.text))
[Address Reference Count : 1]

- startup_stm32f373xc.o(RESET)

RTC_WKUP_IRQHandler (Thumb, 0 bytes, Stack size 0 bytes, startup_stm32f373xc.o(.text))
[Address Reference Count : 1]

- startup_stm32f373xc.o(RESET)

SDADC1_IRQHandler (Thumb, 0 bytes, Stack size 0 bytes, startup_stm32f373xc.o(.text))
[Address Reference Count : 1]

- startup_stm32f373xc.o(RESET)

SDADC2_IRQHandler (Thumb, 0 bytes, Stack size 0 bytes, startup_stm32f373xc.o(.text))
[Address Reference Count : 1]

- startup_stm32f373xc.o(RESET)

SDADC3_IRQHandler (Thumb, 0 bytes, Stack size 0 bytes, startup_stm32f373xc.o(.text))
[Address Reference Count : 1]

- startup_stm32f373xc.o(RESET)

SPI1_IRQHandler (Thumb, 0 bytes, Stack size 0 bytes, startup_stm32f373xc.o(.text))
[Address Reference Count : 1]

- startup_stm32f373xc.o(RESET)

SPI2_IRQHandler (Thumb, 0 bytes, Stack size 0 bytes, startup_stm32f373xc.o(.text))
[Address Reference Count : 1]

- startup_stm32f373xc.o(RESET)

SPI3_IRQHandler (Thumb, 0 bytes, Stack size 0 bytes, startup_stm32f373xc.o(.text))
[Address Reference Count : 1]

- startup_stm32f373xc.o(RESET)

TAMP_STAMP_IRQHandler (Thumb, 0 bytes, Stack size 0 bytes, startup_stm32f373xc.o(.text))
[Address Reference Count : 1]

- startup_stm32f373xc.o(RESET)

TIM12_IRQHandler (Thumb, 0 bytes, Stack size 0 bytes, startup_stm32f373xc.o(.text))
[Address Reference Count : 1]

- startup_stm32f373xc.o(RESET)

TIM13_IRQHandler (Thumb, 0 bytes, Stack size 0 bytes, startup_stm32f373xc.o(.text))
[Address Reference Count : 1]

- startup_stm32f373xc.o(RESET)

TIM14_IRQHandler (Thumb, 0 bytes, Stack size 0 bytes, startup_stm32f373xc.o(.text))
[Address Reference Count : 1]

- startup_stm32f373xc.o(RESET)
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

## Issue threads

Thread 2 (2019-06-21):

Expand to have more libre hardware

oriansj-som, 2019-06-21:
If you were to replace the STM32F! with an iCE40 FPGA
https://www.youtube.com/watch?v=SOn0g3k0FlE
http://www.clifford.at/icestorm/

Your multimeter will allow more expansive enhancements in the future

MartinD-CZ, 2019-06-21:
Hi, honestly, the hard part about his project is not the digital half - the Cortex-M3 is more than capable of driving a display and doing relatively simple calculations - but the analog front end is the more important part of this project. And I'm afraid an FPGA won't help much with that...

Closed 2019-06-21.

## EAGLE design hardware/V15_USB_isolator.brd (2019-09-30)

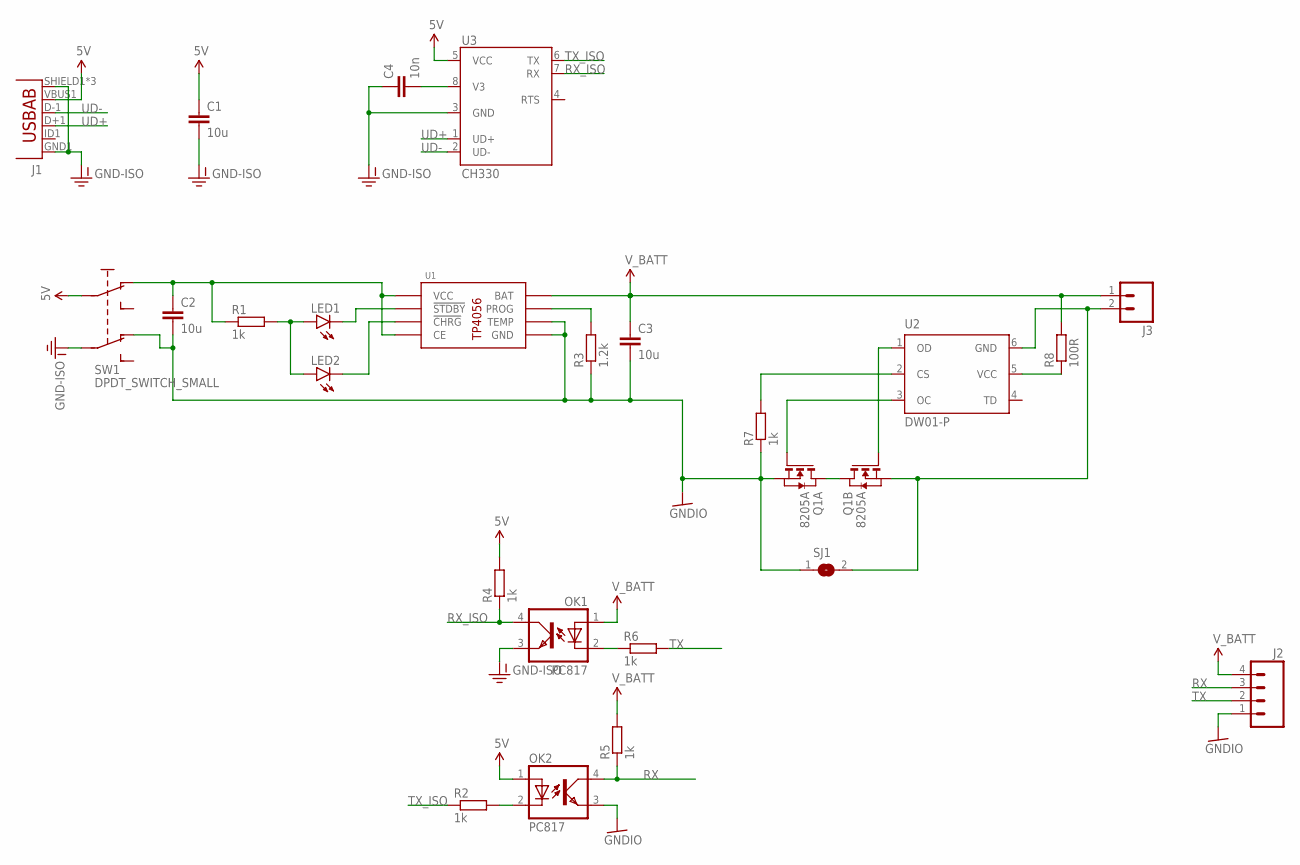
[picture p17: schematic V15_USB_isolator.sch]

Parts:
C1, C2, C3: 10u; C1206
C4: 10n; C1206
J1: USB-ABCONN-11794; USB-AB-MICRO-SMD_V03
J2: M04PTH; 1X04@1
J3: M02PTH3; 1X02_LONGPADS
LED1, LED2: LED1206-BOTTOM; LED-1206-BOTTOM
OK1, OK2: PC817; DIL04
Q1: 8205A; TSSOP8
R1, R2, R4, R5, R6, R7: 1k; R1206
R3: 1.2k; R1206
R8: 100R; R1206
SJ1: SJ
SW1: DPDT_SWITCH_SMALL; DPDT_SMALL
U1: TP4056; SOP8
U2: DW01-P; SOT23-6L
U3: CH330; SO08

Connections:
5V: C1.1, J1.VBUS1 (VBUS), OK2.1 (A), R4.2, SW1.P$2 (I1), U3.5 (VCC)
5V_ISO: C2.1, R1.1, SW1.P$1 (NC1), U1.4 (VCC), U1.8 (CE)
GND-ISO: C1.2, C4.1, J1.GND1 (GND), J1.SHIELD1 (SHIELD), J1.SHIELD2 (SHIELD), J1.SHIELD3 (SHIELD), OK1.3 (EMIT), SW1.P$5 (I2), U3.3 (GND)
GNDIO: C2.2, C3.2, J2.1, OK2.3 (EMIT), Q1.2 (S), Q1.3 (S), R3.1, R7.1, SJ1.1, SW1.P$6 (NC2), U1.1 (TEMP), U1.3 (GND)
unnamed: C4.2, U3.8 (V3)
unnamed: Q1.1 (D), Q1.8 (D)
unnamed: LED1.A, LED2.A, R1.2
unnamed: LED1.C, U1.6 (!STDBY)
unnamed: LED2.C, U1.7 (!CHRG)
unnamed: R3.2, U1.2 (PROG)
unnamed: OK2.2 (C), R2.2
unnamed: OK1.2 (C), R6.1
unnamed: R8.1, U2.5 (VCC)
unnamed: J3.2, Q1.6 (S), Q1.7 (S), SJ1.2, U2.6 (GND)
unnamed: Q1.5 (G), U2.1 (OD)
unnamed: Q1.4 (G), U2.3 (OC)
unnamed: R7.2, U2.2 (CS)
RX: J2.3, OK2.4 (COL), R5.1
RX_ISO: OK1.4 (COL), R4.1, U3.7 (RX)
TX: J2.2, R6.2
TX_ISO: R2.1, U3.6 (TX)
UD+: J1.D+1 (D+), U3.1 (UD+)
UD-: J1.D-1 (D-), U3.2 (UD-)
V_BATT: C3.1, J2.4, J3.1, OK1.1 (A), R5.2, R8.2, U1.5 (BAT)

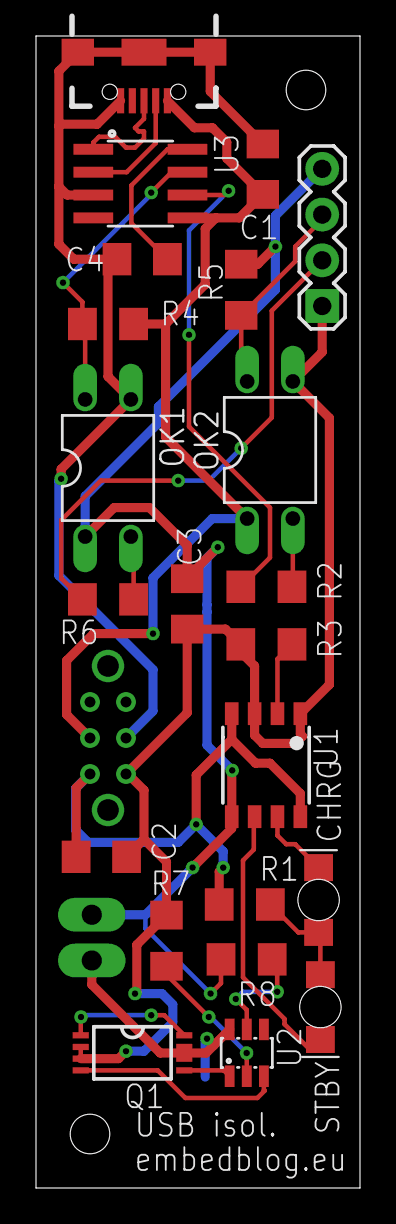
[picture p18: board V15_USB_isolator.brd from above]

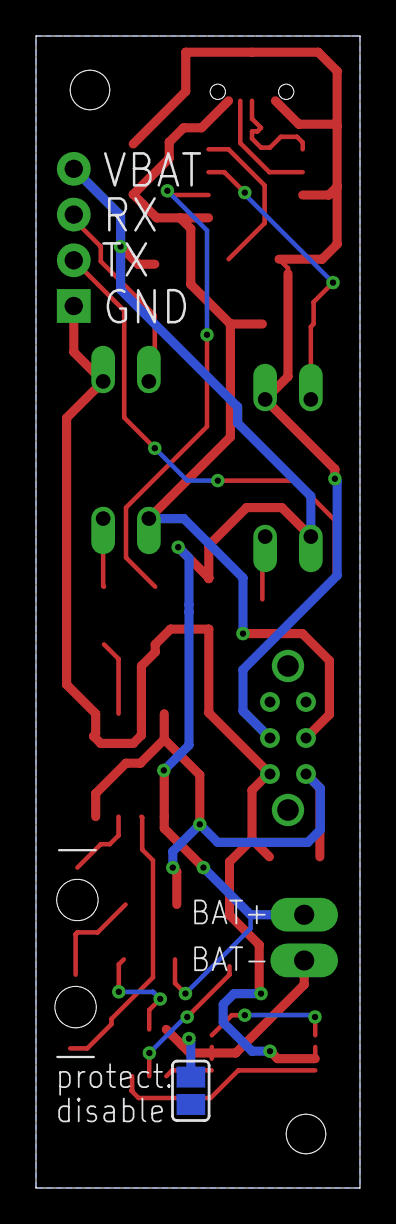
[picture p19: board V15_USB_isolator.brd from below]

Board: 2 copper layers, 18.0 x 64.0 mm, 25 parts (2 on the bottom side), 24 nets.

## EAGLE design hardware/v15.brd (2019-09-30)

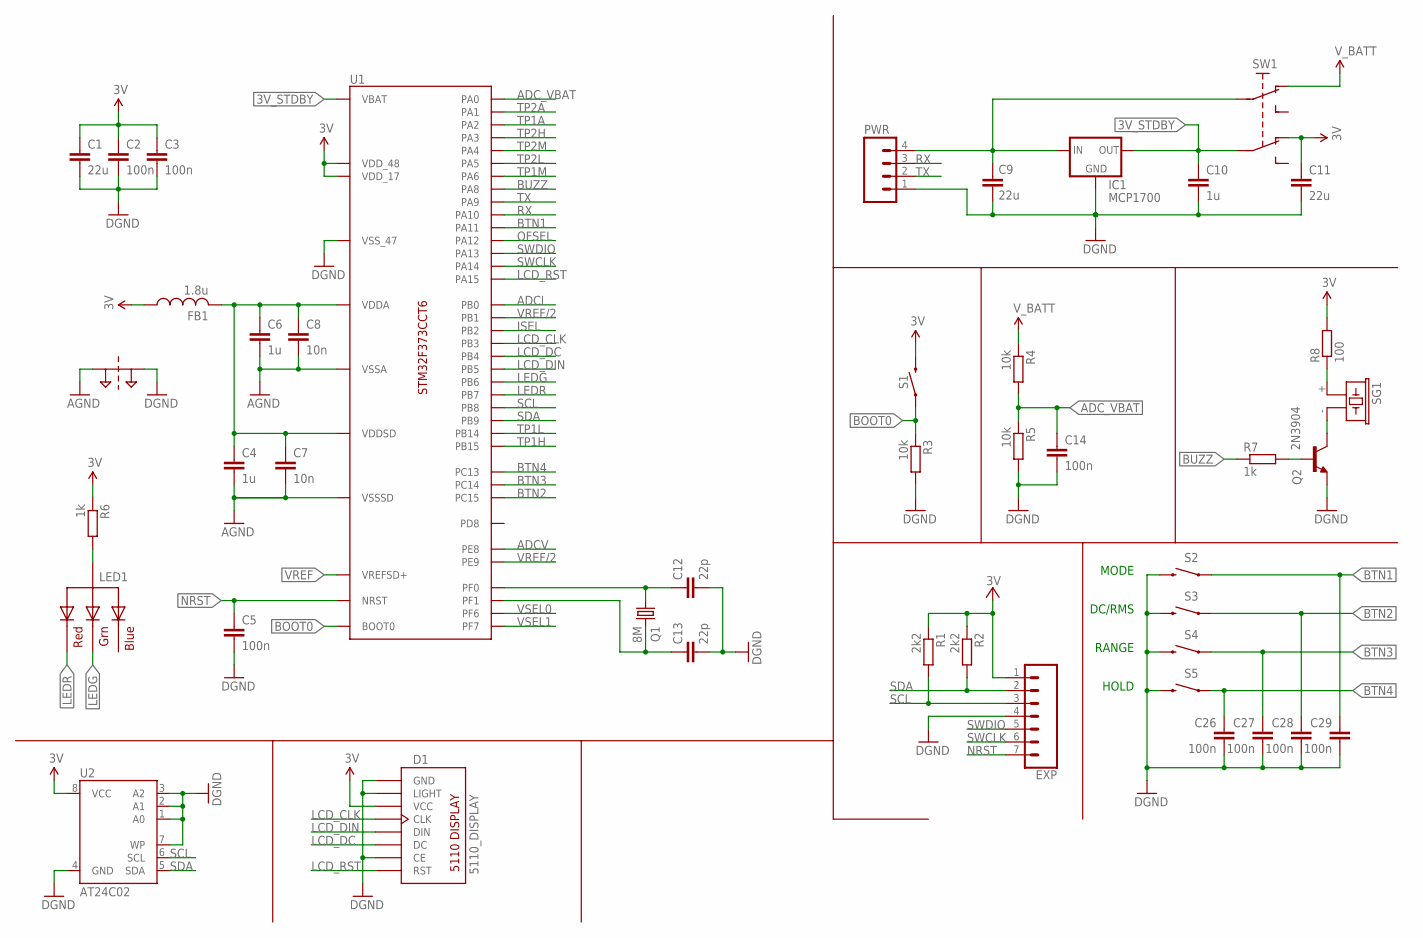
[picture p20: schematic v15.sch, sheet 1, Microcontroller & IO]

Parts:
C1, C9, C11: 22u; C1206
C2, C3, C5, C14, C26, C27, C28, C29: 100n; C1206
C4, C6, C10: 1u; C1206
C7, C8: 10n; C1206
C12, C13: 22p; C1206
D1: 5110_DISPLAY; 5110_LAYOUT
EXP: CONN_07; 1X07
FB1: 1.8u; 1206
IC1: MCP1700; SOT23
LED1: RGBLED_CA-5MM; LED5MMRGB
PT1: 2PT_GND_TIE
PWR: M04PTH; 1X04@1
Q1: 8M; HC49U-V
Q2: 2N3904; SOT23
R1, R2: 2k2; R1206
R3, R4, R5: 10k; R1206
R6, R7: 1k; R1206
R8: 100; R1206
S1: MOMENTARY-SWITCH-SPST-PTH-6.0MM; TACTILE_SWITCH_PTH_6.0MM
S2, S3, S4, S5: MOMENTARY-SWITCH-SPST-SMD-12MM; TACTILE_SWITCH_SMD_12MM
SG1: F/CM12P
SW1: DPDT_SWITCH_SMALL; DPDT_SMALL
U1: STM32F373CCT6; LQFP-48
U2: AT24C02; SOIC8

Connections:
3V: C1.1, C2.1, C3.1, C11.1, D1.VCC, EXP.1, FB1.1, R1.1, R2.1, R6.1, R8.2, S1.3 (2), SW1.P$6 (NC2), U1.17 (VDD_17), U1.48 (VDD_48), U2.8 (VCC); also elsewhere on the board
3V_STDBY: C10.1, IC1.2 (OUT), SW1.P$5 (I2), U1.1 (VBAT)
ADCI: U1.18 (PB0); also elsewhere on the board
ADCV: U1.21 (PE8); also elsewhere on the board
ADC_VBAT: C14.1, R4.2, R5.1, U1.10 (PA0)
AGND: C4.2, C6.2, C7.2, C8.2, PT1.P$1, U1.8 (VSSA), U1.23 (VSSSD); also elsewhere on the board
BOOT0: R3.1, S1.1, U1.44 (BOOT0)
BTN1: C29.1, S2.1, U1.32 (PA11)
BTN2: C28.1, S3.1, U1.4 (PC15)
BTN3: C27.1, S4.1, U1.3 (PC14)
BTN4: C26.1, S5.1, U1.2 (PC13)
BUZZ: R7.1, U1.29 (PA8)
GND: C1.2, C2.2, C3.2, C5.2, C9.2, C10.2, C11.2, C12.2, C13.2, C14.2, C26.2, C27.2, C28.2, C29.2, D1.CE, D1.GND, D1.LIGHT, EXP.4, IC1.1 (GND), PT1.P$2, PWR.1, Q2.2 (E), R3.2, R5.2, S2.3 (2), S3.3 (2), S4.3 (2), S5.3 (2), U1.47 (VSS_47), U2.1 (A0), U2.2 (A1), U2.3 (A2), U2.4 (GND), U2.7 (WP)
ISEL: U1.20 (PB2); also elsewhere on the board
LCD_CLK: D1.CLK, U1.39 (PB3)
LCD_DC: D1.DC, U1.40 (PB4)
LCD_DIN: D1.DIN, U1.41 (PB5)
LCD_RST: D1.RST, U1.38 (PA15)
LEDG: LED1.3 (GREEN), U1.42 (PB6)
LEDR: LED1.1 (RED), U1.43 (PB7)
unnamed: C12.1, Q1.1, U1.5 (PF0)
unnamed: C4.1, C6.1, C7.1, C8.1, FB1.2, U1.9 (VDDA), U1.24 (VDDSD)
unnamed: C9.1, IC1.3 (IN), PWR.4, SW1.P$2 (I1)
unnamed: LED1.2 (VCC), R6.2
unnamed: R8.1, SG1.+ (1)
unnamed: C13.1, Q1.2, U1.6 (PF1)
unnamed: Q2.3 (C), SG1.- (2)
unnamed: Q2.1 (B), R7.2
NRST: C5.1, EXP.7, U1.7 (NRST)
OFSEL: U1.33 (PA12); also elsewhere on the board
RX: PWR.3, U1.31 (PA10)
SCL: EXP.3, R1.2, U1.45 (PB8), U2.6 (SCL)
SDA: EXP.2, R2.2, U1.46 (PB9), U2.5 (SDA)
SWCLK: EXP.6, U1.37 (PA14)
SWDIO: EXP.5, U1.34 (PA13)
TP1A: U1.12 (PA2); also elsewhere on the board
TP1H: U1.27 (PB15); also elsewhere on the board
TP1L: U1.26 (PB14); also elsewhere on the board
TP1M: U1.16 (PA6); also elsewhere on the board
TP2A: U1.11 (PA1); also elsewhere on the board
TP2H: U1.13 (PA3); also elsewhere on the board
TP2L: U1.15 (PA5); also elsewhere on the board
TP2M: U1.14 (PA4); also elsewhere on the board
TX: PWR.2, U1.30 (PA9)
VREF: U1.25 (VREFSD+); also elsewhere on the board
VREF/2: U1.19 (PB1), U1.22 (PE9); also elsewhere on the board
VSEL0: U1.35 (PF6); also elsewhere on the board
VSEL1: U1.36 (PF7); also elsewhere on the board
V_BATT: R4.1, SW1.P$1 (NC1)

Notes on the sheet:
MODE
RANGE
DC/RMS
HOLD

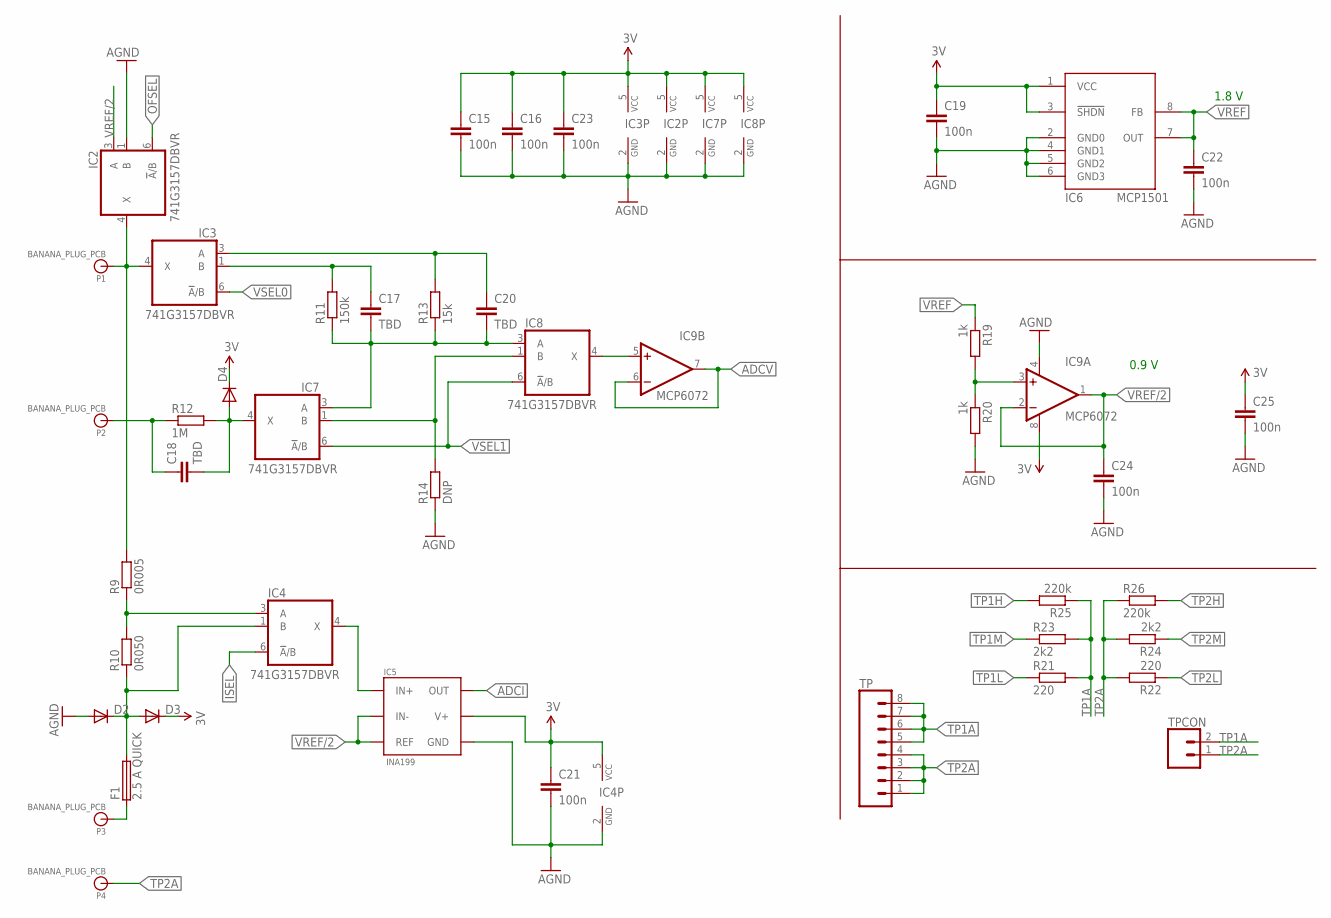
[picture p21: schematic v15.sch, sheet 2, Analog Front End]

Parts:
C15, C16, C21, C23: 100n; 1206
C17, C18, C20: TBD; 1206
C19, C22, C24, C25: 100n; C1206
D2, D3, D4: DIODE-MINIMELF; MINIMELF
F1: 2.5 A QUICK; SHK20L
IC2, IC3, IC4, IC7, IC8: 741G3157DBVR; DBV_R-PDSO-G6
IC5: INA199; SC70-6
IC6: MCP1501; SO08
IC9: MCP6072; SO08
P1, P2, P3, P4: BANANA_PLUG_PCB; BANANA_6MMHOLE
R9: 0R005; R1206
R10: 0R050; R1206
R11: 150k; R1206
R12: 1M; R1206
R13: 15k; R1206
R14: DNP; R1206
R19, R20: 1k; R1206
R21, R22: 220; R1206
R23, R24: 2k2; R1206
R25, R26: 220k; R1206
TP: CONN_08SMD-STRAIGHT-FEMALE; 1X08_SMD
TPCON: CONN_02; 1X02

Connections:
3V: C15.1, C16.1, C19.1, C21.1, C23.1, C25.1, D3.C, D4.C, IC2.5 (VCC), IC3.5 (VCC), IC4.5 (VCC), IC5.3 (V+), IC6.1 (VCC), IC6.3 (!SHDN), IC7.5 (VCC), IC8.5 (VCC), IC9.8 (V+); also elsewhere on the board
ADCI: IC5.6 (OUT); also elsewhere on the board
ADCV: IC9.6 (-IN), IC9.7 (OUT); also elsewhere on the board
AGND: C15.2, C16.2, C19.2, C21.2, C22.2, C23.2, C24.2, C25.2, D2.A, IC2.1 (B), IC2.2 (GND), IC3.2 (GND), IC4.2 (GND), IC5.2 (GND), IC6.2 (GND0), IC6.4 (GND1), IC6.5 (GND2), IC6.6 (GND3), IC7.2 (GND), IC8.2 (GND), IC9.4 (V-), R14.1, R20.2; also elsewhere on the board
COM: IC2.4 (X), IC3.4 (X), P1.P$1, R9.2
ISEL: IC4.6 (!A!/B); also elsewhere on the board
unnamed: C18.1, P2.P$1, R12.1
unnamed: C17.1, IC3.1 (B), R11.2
unnamed: C20.1, IC3.3 (A), R13.2
unnamed: C18.2, D4.A, IC7.4 (X), R12.2
unnamed: IC4.3 (A), R9.1, R10.2
unnamed: C17.2, C20.2, IC7.3 (A), IC8.3 (A), R11.1, R13.1
unnamed: D2.C, D3.A, F1.2A (2), IC4.1 (B), R10.1
unnamed: IC8.4 (X), IC9.5 (+IN)
unnamed: IC7.1 (B), IC8.1 (B), R14.2
unnamed: IC9.3 (+IN), R19.2, R20.1
unnamed: IC4.4 (X), IC5.4 (IN+)
unnamed: F1.1A (1), P3.P$1
OFSEL: IC2.6 (!A!/B); also elsewhere on the board
TP1A: R21.2, R23.2, R25.1, TP.5, TP.6, TP.7, TP.8, TPCON.2; also elsewhere on the board
TP1H: R25.2; also elsewhere on the board
TP1L: R21.1; also elsewhere on the board
TP1M: R23.1; also elsewhere on the board
TP2A: P4.P$1, R22.2, R24.2, R26.1, TP.1, TP.2, TP.3, TP.4, TPCON.1; also elsewhere on the board
TP2H: R26.2; also elsewhere on the board
TP2L: R22.1; also elsewhere on the board
TP2M: R24.1; also elsewhere on the board
VREF: C22.1, IC6.7 (OUT), IC6.8 (FB), R19.1; also elsewhere on the board
VREF/2: C24.1, IC2.3 (A), IC5.1 (REF), IC5.5 (IN-), IC9.1 (OUT), IC9.2 (-IN); also elsewhere on the board
VSEL0: IC3.6 (!A!/B); also elsewhere on the board
VSEL1: IC7.6 (!A!/B), IC8.6 (!A!/B); also elsewhere on the board

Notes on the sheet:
1.8 V
0.9 V

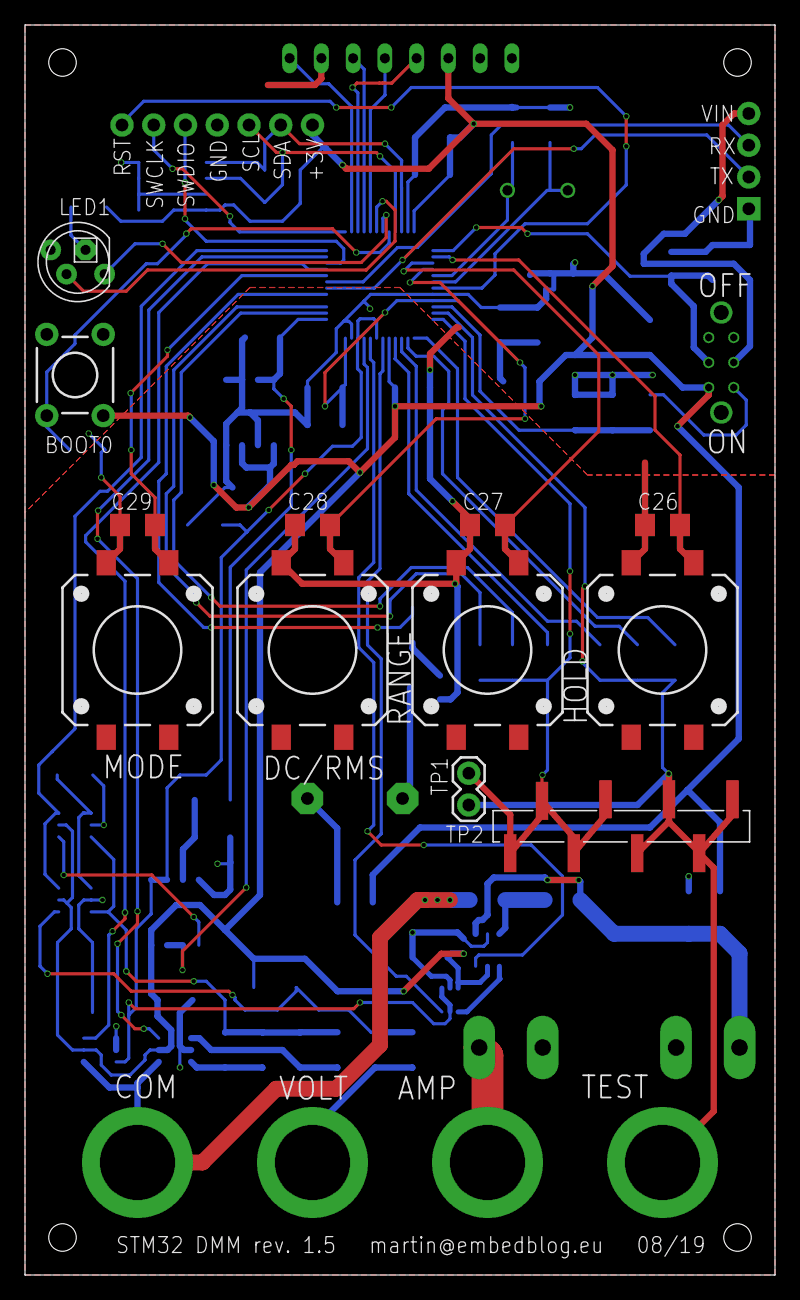
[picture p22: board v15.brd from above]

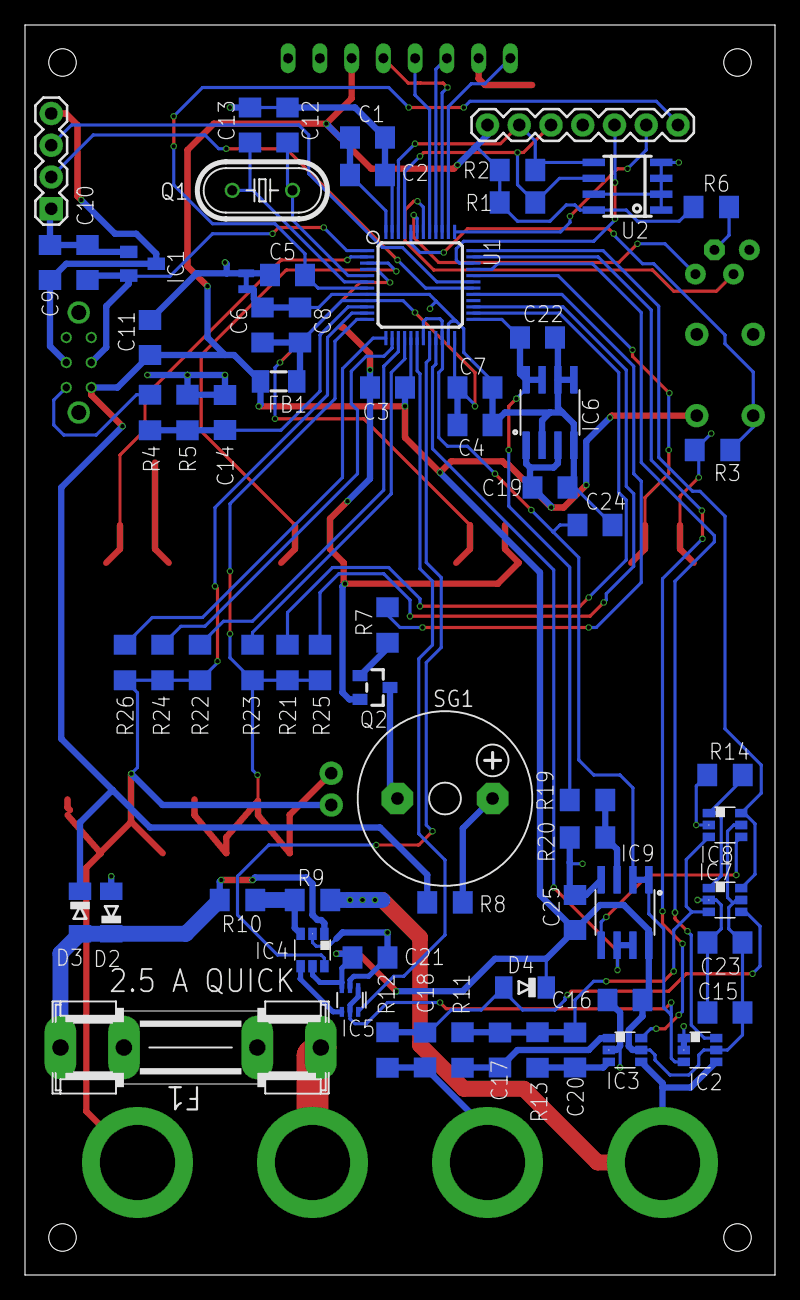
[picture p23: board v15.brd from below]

Board: 2 copper layers, 60.0 x 100.0 mm, 87 parts (69 on the bottom side), 62 nets.

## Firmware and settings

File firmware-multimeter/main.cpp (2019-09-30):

/* ====================================================
 * STM32 OPEN SOURCE MULTIMETER
 * embedblog.eu/dmm
 * license: CC BY-NC-SA 4.0
 * ==================================================== */

#include "stm32f3xx.h"
#include "init.h"
#include "delay.h"
#include "sdadc.h"
#include "interrupt.h"
#include "config.h"
#include "draw.h"

int main(void)
{
	init_RCC();
	init_GPIO();
	LED_NONE;
	init_EXTI();
	_delay_init();
	SDADC_init();
	init_TIM3();
	init_BKP();
	init_TIM2();

	drawSplashScreen();								//this function also contains init for UART, EEPROM and ADC1
	_delay_ms(SPLASH_SCREEN_DUR);
	
	SDADC_start();
	
	while (1)
	{
		drawScreen();		
	}
}

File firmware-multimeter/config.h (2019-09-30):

#ifndef _CONFIG_H
#define _CONFIG_H

//==========================================================================
// USER SETTINGS - modify as you wish
#define SCREEN_TRANSISTION_DUR		1000			//in ms, how long the intro to each screen is displayed
#define SPLASH_SCREEN_DUR					2000			//in ms, how long the start up screen is displayed
#define SCREEN_UPDATE_RATE				2					//in Hz, how often is the measurement (V, I or P) screen refreshed
#define CONTINUITY_REFRESH				10				//in Hz, how often is the continuity screen refreshed

#define CONTINUITY_BUZZER					50				//in ohms, below this value the buzzer is sounded
#define IO_COMPENSATION						23

#define VREF											1.8f
#define VSUP											2.99f			//TODO: add to EEPROM

//#define RAW_OUTPUT

//==========================================================================
// SYSTEM SETTINGS - do not modify, unless you know what you're doing
#define BUZZER_ON						GPIOA->BSRR = GPIO_BSRR_BS_8
#define BUZZER_OFF					GPIOA->BSRR = GPIO_BSRR_BR_8

#define VSEL0_LOW						GPIOF->BSRR = GPIO_BSRR_BR_6
#define VSEL0_HIGH					GPIOF->BSRR = GPIO_BSRR_BS_6
#define VSEL1_LOW						GPIOF->BSRR = GPIO_BSRR_BR_7
#define VSEL1_HIGH					GPIOF->BSRR = GPIO_BSRR_BS_7

#define ISEL_HIGH						GPIOB->BSRR = GPIO_BSRR_BS_2
#define ISEL_LOW						GPIOB->BSRR = GPIO_BSRR_BR_2

#define OFSEL_GND						GPIOA->BSRR = GPIO_BSRR_BS_12
#define OFSEL_VREF2					GPIOA->BSRR = GPIO_BSRR_BR_12

#define LED_RED							GPIOB->BSRR = GPIO_BSRR_BS_6 | GPIO_BSRR_BR_7
#define LED_GREEN						GPIOB->BSRR = GPIO_BSRR_BR_6 | GPIO_BSRR_BS_7
#define LED_NONE						GPIOB->BSRR = GPIO_BSRR_BS_6 | GPIO_BSRR_BS_7

#define MODE_VOLTAGE				0
#define MODE_CURRENT				1
#define MODE_POWER					2
#define MODE_CONT						3
#define MODE_COMPTEST				4
#define MODE_FREQUENCY			5
#define MODES								6

#define DATA_SAVED					0xC0

//==========================================================================
// COMPONENT TEST IO
#define TP1L_HIGHZ					GPIOB->MODER &=~ GPIO_MODER_MODER14
#define TP1L_LOW						GPIOB->MODER |= GPIO_MODER_MODER14_0; GPIOB->BSRR = GPIO_BSRR_BR_14
#define TP1L_HIGH						GPIOB->MODER |= GPIO_MODER_MODER14_0; GPIOB->BSRR = GPIO_BSRR_BS_14

#define TP1M_HIGHZ					GPIOA->MODER &=~ GPIO_MODER_MODER6
#define TP1M_LOW						GPIOA->MODER |= GPIO_MODER_MODER6_0; GPIOA->BSRR = GPIO_BSRR_BR_6
#define TP1M_HIGH						GPIOA->MODER |= GPIO_MODER_MODER6_0; GPIOA->BSRR = GPIO_BSRR_BS_6

#define TP1H_HIGHZ					GPIOB->MODER &=~ GPIO_MODER_MODER15
#define TP1H_LOW						GPIOB->MODER |= GPIO_MODER_MODER15_0; GPIOB->BSRR = GPIO_BSRR_BR_15
#define TP1H_HIGH						GPIOB->MODER |= GPIO_MODER_MODER15_0; GPIOB->BSRR = GPIO_BSRR_BS_15

#define TP1A_ANALOG					GPIOA->MODER |= GPIO_MODER_MODER2
#define TP1A_LOW						GPIOA->MODER &=~GPIO_MODER_MODER2_1; GPIOB->BSRR = GPIO_BSRR_BR_2
#define TP1A_HIGH						GPIOA->MODER &=~GPIO_MODER_MODER2_1; GPIOB->BSRR = GPIO_BSRR_BS_2

#define TP2L_HIGHZ					GPIOA->MODER &=~ GPIO_MODER_MODER5
#define TP2L_LOW						GPIOA->MODER |= GPIO_MODER_MODER5_0; GPIOA->BSRR = GPIO_BSRR_BR_5
#define TP2L_HIGH						GPIOA->MODER |= GPIO_MODER_MODER5_0; GPIOA->BSRR = GPIO_BSRR_BS_5

#define TP2M_HIGHZ					GPIOA->MODER &=~ GPIO_MODER_MODER4
#define TP2M_LOW						GPIOA->MODER |= GPIO_MODER_MODER4_0; GPIOA->BSRR = GPIO_BSRR_BR_4
#define TP2M_HIGH						GPIOA->MODER |= GPIO_MODER_MODER4_0; GPIOA->BSRR = GPIO_BSRR_BS_4

#define TP2H_HIGHZ					GPIOA->MODER &=~ GPIO_MODER_MODER3
#define TP2H_LOW						GPIOA->MODER |= GPIO_MODER_MODER3_0; GPIOA->BSRR = GPIO_BSRR_BR_3
#define TP2H_HIGH						GPIOA->MODER |= GPIO_MODER_MODER3_0; GPIOA->BSRR = GPIO_BSRR_BS_3

#define TP2A_ANALOG					GPIOA->MODER |= GPIO_MODER_MODER1
#define TP2A_LOW						GPIOA->MODER &=~GPIO_MODER_MODER1_1; GPIOB->BSRR = GPIO_BSRR_BR_1
#define TP2A_HIGH						GPIOA->MODER &=~GPIO_MODER_MODER1_1; GPIOB->BSRR = GPIO_BSRR_BS_1

#endif

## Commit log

2019-05-27 V1.2b
    initial release
    [case_bottom.SLDPRT, case_bottom.STL, case_side.SLDPRT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]
2019-06-26 added experimental rev 1.3
    see my blog for more info
    [v13.brd, v13.sch]
2019-09-30 rev 1.5
    ton of new features, see the blog
    [V15_USB_isolator.brd, V15_USB_isolator.sch, v12.brd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]
2019-10-02 updated files for 3D printing
    [body.SLDPRT, body.STL, bottom.SLDPRT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]

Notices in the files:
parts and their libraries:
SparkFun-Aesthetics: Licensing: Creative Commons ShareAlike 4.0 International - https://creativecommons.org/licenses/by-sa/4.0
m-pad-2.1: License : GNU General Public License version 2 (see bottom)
